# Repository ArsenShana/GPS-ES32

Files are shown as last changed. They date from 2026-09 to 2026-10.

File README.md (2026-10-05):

# AlanaTech GPS — трекер на ESP32 + LoRa E32

```
 [NEO-6M] ──UART──> [ESP32 трекер] ──[E32 433 МГц]))) ~~~ (((  [E32]──> [ESP32 приёмник] ──Wi-Fi──> браузер
```

| Папка | Что это |
|---|---|
| [gps_tracker/](gps_tracker/) | ESP32 + NEO-6M + E32: раз в 5 с отправляет координаты по радио |
| [gps_receiver/](gps_receiver/) | ESP32 + E32: принимает пакеты, подключается к Wi-Fi `New BilimLand Wi-Fi`, показывает карту |

Оба проекта — PlatformIO (VS Code → расширение PlatformIO IDE).

## Плата без проводов и 3D-модель

В `tracker-lab/` добавлены локальный сайт с интерактивной 3D-моделью, симуляция
радиообмена, программно разведённая плата-носитель KiCad и корпус STL/STEP.
Запуск сайта: `cd tracker-lab` → `npm ci` → `npm start`, затем открыть
`http://localhost:4173`. Инструкция по сборке и прошивке: `tracker-lab/README.html`.

Носитель R0 рассчитан на **ESP32-DevKitC V4 WROOM с 38 контактами**, NEO-6M
breakout и E32-433T30D. Это прототип: разъёмы нужно сверить с вашими модулями,
KiCad DRC/ERC и физические испытания ещё не выполнены. Герберы пока не выпущены.
Для носителя добавлены среды `carrier` и `carrier_fake` с AUX на GPIO19;
передача пропускается при ошибке конфигурации E32 или таймауте AUX.

Вторая версия **AT-02 V2** находится в `tracker-lab/v2/` и открывается по
`http://localhost:4173/v2/`. Это собственная SMD-архитектура на STM32L072CBT6
с MAX-M10S, E32-433T20S, USB-C, LiPo/PowerPath, buck-boost 3.3 В и датчиком
движения. Arduino/ESP32-DevKit не используются. Подготовлены нумерованная
KiCad-схема, netlist, компоновка PCB 68×44 мм, корпус и отдельная 3D-модель.
Статус V2 — инженерный проект A0: финальная трассировка, RF, уточнение некоторых
посадочных мест и DRC/ERC ещё нужны; Gerber не выпущены. Ядро логики написано
на C и проверено на компьютере, но полный STM32-порт и физические испытания
пока не выполнены. ESP32-прошивку R0 нельзя загружать в V2.

## Подключение

E32 — одинаково на обеих платах:

| E32-433T30D | ESP32 трекер | ESP32 приёмник |
|---|---|---|
| VCC | **5V (VIN)** — не 3.3V! | **5V (VIN)** |
| GND | GND | GND |
| TXD | GPIO16 | GPIO16 |
| RXD | GPIO17 | GPIO17 |
| M0 | GPIO25 | GPIO25 |
| M1 | GPIO26 | GPIO26 |
| AUX | GPIO27 (можно не подключать) | GPIO27 (можно не подключать) |

Только на трекере — NEO-6M (без GPS прошивайте `tracker_fake`):

| NEO-6M | ESP32 |
|---|---|
| VCC | 3.3V (или 5V, если на модуле есть стабилизатор) |
| GND | GND |
| TX | GPIO32 |
| RX | GPIO33 |

> ⚠️ **Никогда не включайте E32 без антенны** — на мощности 1 Вт выходной каскад сгорит.
> ⚠️ E32-433T30D при передаче берёт до ~700 мА. Питание от USB ноутбука может «проседать» —
> тогда ESP32 перезагружается (brownout). Поставьте конденсатор 470–1000 мкФ между VCC и GND модуля.
> При тесте на столе антенны должны быть на расстоянии хотя бы 1–2 м (1 Вт вплотную перегружает приёмник).

Пины меняются в `include/config.h` каждого проекта.

## Параметры радио

Обе прошивки при старте сами проверяют и при необходимости записывают одинаковую конфигурацию E32:
433 МГц (канал 0x17), адрес 0x0000, UART 9600, скорость в эфире 2.4 кбит/с, FEC, 30 дБм, прозрачный режим.

Формат пакета (≤ 58 байт, один радиопакет E32) описан в `lib/GpsProtocol/GpsProtocol.h`:
```
G,1,1234,1,51.128207,71.430411,347,12.3,9,0.9*50
```

## Прошивка

Плата подключается по Type-C и видна как `USB-SERIAL CH340 (COMx)`. Если порт не появился —
кабель только для зарядки, нужен кабель с передачей данных.

**Режим прошивки.** На этих платах автоматический вход в загрузчик не срабатывает
(ошибка `Wrong boot mode detected (0x13)`), поэтому перед каждой прошивкой:
1. зажать **BOOT**;
2. нажать и отпустить **EN** (RST);
3. отпустить **BOOT** — плата ждёт прошивку, пока её не перезагрузят.

```bash
# трекер
cd gps_tracker
pio run -e tracker -t upload && pio device monitor

# приёмник
cd gps_receiver
pio run -e receiver -t upload && pio device monitor
```

Если PlatformIO не установлен в VS Code, вместо `pio` используйте `py -3.11 -m platformio`.

`lib/GpsProtocol` и `lib/E32` одинаковые в обеих папках — при изменении правьте обе копии.

Ход тестирования и найденные ошибки — в [TESTING.md](TESTING.md).

## Тестирование

### 1. Юнит-тесты протокола (без железа, на ПК)
```bash
cd gps_tracker  && pio test -e native
cd gps_receiver && pio test -e native
```
Проверяют кодирование/декодирование, отбрасывание битых и обрезанных пакетов, помещение в 58 байт, подсчёт потерь.
Нужен gcc в PATH (например, MSYS2 `C:\msys64\mingw64\bin`).

### 2. Проверка каждого модуля (Serial-монитор, 115200)
- Трекер: должно быть `[E32] конфигурация ОК` и строки `[GPS] символов=...` с растущим числом.
  Если `символов=0` — неправильно подключён TX NEO-6M.
- Приёмник: `[E32] конфигурация ОК`, `[WiFi] подключено, IP: ...`.
  Если Wi-Fi не подключился, прошивка печатает код причины и список видимых сетей
  (201 — сеть не найдена: проверьте имя с учётом регистра и что сеть на 2.4 ГГц).

### 3. Радиоканал без GPS (в помещении)
Прошейте трекер тестовой прошивкой — она шлёт координаты по кругу вокруг центра Астаны:
```bash
cd gps_tracker && pio run -e tracker_fake -t upload
```
В логе приёмника появятся строки `[RX] id=1 seq=... fix=1 ...`, на странице `http://<IP приёмника>/` — движущаяся точка.

### 4. Автоматическая проверка связи с ПК
ПК должен быть в той же Wi-Fi сети:
```bash
python gps_receiver/tools/link_test.py <IP приёмника> -t 120
```
В конце — итог: принято / потеряно / % потерь и вердикт.

### 5. Настоящий GPS
Прошейте `-e tracker`, вынесите трекер на улицу или к окну. Холодный старт NEO-6M — до 5 минут
(на модуле замигает светодиод, когда есть фикс). На странице бейдж станет «GPS фикс», на карте появится трек.

## Веб-интерфейс приёмника

| Адрес | Что |
|---|---|
| `/` | карта + данные |
| `/api/last` | последний пакет, JSON |
| `/api/history` | трек (до 200 точек), JSON |
| `/api/status` | статистика приёма, Wi-Fi |
| `POST /api/reset` | сброс статистики |

Также доступно по `http://alanatech-gps.local/` (если сеть/ОС поддерживает mDNS).
Карта грузится из интернета (OpenStreetMap), таблица работает и без него.

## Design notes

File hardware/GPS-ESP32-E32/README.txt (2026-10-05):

GPS-ESP32-E32 — плата-носитель R0, 100 × 78 мм, 2 слоя, FR4 1.6 мм.

Открыть GPS-ESP32-E32.kicad_pro в KiCad. Рядом находятся редактируемая
схема .kicad_sch, разведённая плата .kicad_pcb, локальные библиотеки,
PDF схемы и платы, BOM.csv и отчёты DRC/ERC.

Модули: ESP32-DevKitC V4 WROOM, 38 контактов (19 на сторону,
25.4 мм между рядами); NEO-6M breakout; E32-433T30D.
J2/J3 — гнёзда ESP32, J4 — GPS, J5 — E32, J1 — вход 5 В.
GPS J4: 1=3V3, 2=RX, 3=TX, 4=GND.
E32 J5: 1=M0, 2=M1, 3=RXD, 4=TXD, 5=AUX, 6=5V, 7=GND.

Точная разводка GPIO:
GPS TX -> GPIO16, GPS RX <- GPIO17.
E32 TXD -> GPIO26, E32 RXD <- GPIO27.
E32 M0 <- GPIO25, E32 M1 <- GPIO18, E32 AUX -> GPIO19.
Индикатор: GPIO2 -> R1 330 Ом -> анод D1; катод D1 -> GND.

Прошивка из gps_tracker:
  pio run -e kicad_r0 -t upload
Для демонстрационных координат:
  pio run -e kicad_r0_fake -t upload
Обычные tracker/carrier имеют другую распиновку и не подходят этой разводке.

Питание: внешний стабилизированный источник 5 В / 2 А на J1.
E32 питается от 5 В, GPS — от 3.3 В ESP32. C1 1000 мкФ / 10 В
и C2 100 нФ установлены на шине 5 В возле радио.
JP1 соединяет внешний источник с 5V ESP32: снять перемычку до
подключения USB ESP32. Не подавать автомобильные 12/24 В напрямую.
Перед включением радио подключить подходящую антенну 433 МГц.

Проверено KiCad 10.0.6: DRC — 0 нарушений, 0 неподключённых;
ERC — 0 нарушений. Символы описывают пассивные контакты разъёмов:
ERC не проверяет внутренние цепи модулей и совместимость уровней.
Статус: прототип. До изготовления сверить габариты и порядок контактов
реальных модулей, гнёзда E32, полярность LED и конденсатора, проверить
питание и работу на стенде. Геометрия SMD-площадок упрощена.
Герберы для производства не выпускались.

Повторный экспорт проекта:
  python3 tracker-lab/tools/export_kicad_project.py
PDF и DRC/ERC обновляются отдельно через kicad-cli.

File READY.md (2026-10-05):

# AlanaTech GPS — отчёт о готовности

**Дата:** 2026-09-26 · **Версия:** 0.0.1 beta · **Общий статус:** 🟡 прошивки написаны и работают на платах по отдельности,
**радиосвязь трекер → приёмник пока не подтверждена**.

## Итог в одном абзаце

Обе прошивки написаны, собираются и залиты на платы. Каждый ESP32 видит свой модуль E32 и
записывает в него одинаковые настройки радио. Приёмник подключается к Wi-Fi и показывает веб-страницу
с картой. Трекер каждые 5 секунд отправляет пакет в эфир. Но **приёмник пока не получил ни одного пакета** —
причина в радиочасти (антенны / питание / расстояние), а не в проводах к ESP32 и не в прошивке.
GPS в офисе фикс не поймает — это ожидаемо, для координат нужно окно или улица.

## ✅ Что работает (проверено на железе)

| Компонент | Результат проверки |
|---|---|
| Прошивка приёмника | залита на ESP32 (COM3), запускается |
| Прошивка трекера | залита на ESP32 (COM4), запускается |
| E32 на приёмнике | отвечает, конфигурация `C0 00 00 1A 17 44` записана и прочитана обратно |
| E32 на трекере | отвечает, та же конфигурация — провода UART и M0/M1 исправны |
| Трекер: отправка пакетов | каждые 5 с, пакеты `G,1,<seq>,...*CS` уходят в E32 |
| Приёмник: Wi-Fi | подключён к `New BilimLand Wi-Fi`, IP **192.168.8.183** |
| Приёмник: веб-страница и API | `http://192.168.8.183/`, `/api/status`, `/api/last` отвечают с ПК |
| Протокол пакетов | 7/7 юнит-тестов на ПК: кодирование, контрольная сумма, битые/обрезанные пакеты, ≤ 58 байт |
| Сборка | `tracker`, `tracker_fake`, `receiver` — без ошибок |

## ❌ Что пока не работает

| Проблема | Что известно | Что делать |
|---|---|---|
| **Приёмник не получает пакеты** (ОШ-08) | трекер отправил 8+ пакетов, приёмник получил 0 байт. Провода к ESP32 исключены — оба E32 отвечают | проверить антенны на **обоих** E32, питание VCC от **5V/VIN**, разнести модули на 1–2 м, прошить `tracker_fake` (мощность снижена до 21 дБм) |
| **GPS не отдавал данные** (ОШ-07) | прошивка ждала NEO-6M на D32, а он на D16/D17 | ✅ исправлено в коде, **нужно прошить трекер** |

## ⚠️ Риски

- **Слабый Wi-Fi у приёмника:** −71…−84 дБм, есть разрывы и таймауты запросов. Сеть 2.4 ГГц в этом месте слабая
  (ESP32 не умеет 5 ГГц). Приёмник нужно поставить ближе к роутеру.
- **E32 без антенны сгорает** на мощности 1 Вт. Не включать трекер без антенны.
- **Питание:** E32-433T30D при передаче берёт до ~700 мА — от USB ноутбука возможны просадки.
- **Прошивка вручную:** на этих платах автоматический вход в загрузчик не работает —
  нужно BOOT → EN → отпустить BOOT (описано в README).

## ⏳ Не проверено

| Что | Когда можно проверить |
|---|---|
| Пакеты доходят по радио, % потерь (`link_test.py`) | после решения ОШ-08, в офисе |
| NEO-6M выдаёт NMEA (без фикса) | после прошивки трекера, в офисе |
| GPS-фикс, точка и трек на карте | у окна или на улице, холодный старт до 5 мин |
| Дальность связи | на улице, после всего выше |
| Исправление переподключения Wi-Fi (ОШ-06) | при следующей прошивке приёмника |

## Следующие шаги

1. Проверить антенны и питание 5V на обоих E32, разнести модули на 1–2 м.
2. Прошить трекер `tracker_fake` → убедиться, что `rx_ok` на приёмнике растёт.
3. Прошить трекер `tracker` (исправленные пины GPS) → в логе `символов=...` растёт.
4. Прошить приёмник (исправление Wi-Fi), поставить ближе к роутеру.
5. Вынести трекер к окну/на улицу → фикс, точка на карте.
6. Прогнать `python gps_receiver/tools/link_test.py 192.168.8.183 -t 300` и записать % потерь.

## Оборудование

| Плата | Чип | Порт | MAC | E32 (TXD/RXD/M0/M1) | GPS (TX/RX) |
|---|---|---|---|---|---|
| Приёмник | ESP32-D0WD-V3 | COM3 | b4:bf:e9:fc:07:d0 | D16 / D17 / D25 / D26, AUX D27 | — |
| Трекер | ESP32-D0WD-V3 | COM4 | 30:76:f5:a9:e8:e8 | D16 / D17 / D25 / D26, AUX D27 | D32 / D33 |

Радио: 433 МГц (канал 0x17), адрес 0x0000, 2.4 кбит/с в эфире, FEC, 30 дБм (в `tracker_fake` — 21 дБм).

---
Подробный журнал ошибок — [TESTING.md](TESTING.md) · Подключение и прошивка — [README.md](README.md)

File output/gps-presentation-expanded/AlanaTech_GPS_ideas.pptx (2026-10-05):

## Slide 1

ПРОДУКТОВЫЕ ИДЕИ / ДЛЯ ТИМЛИДА

Куда встроить GPS

18 идей применения: от личных вещей до транспорта и фермы

Иллюстрации — концепты возможной интеграции, не готовые изделия.

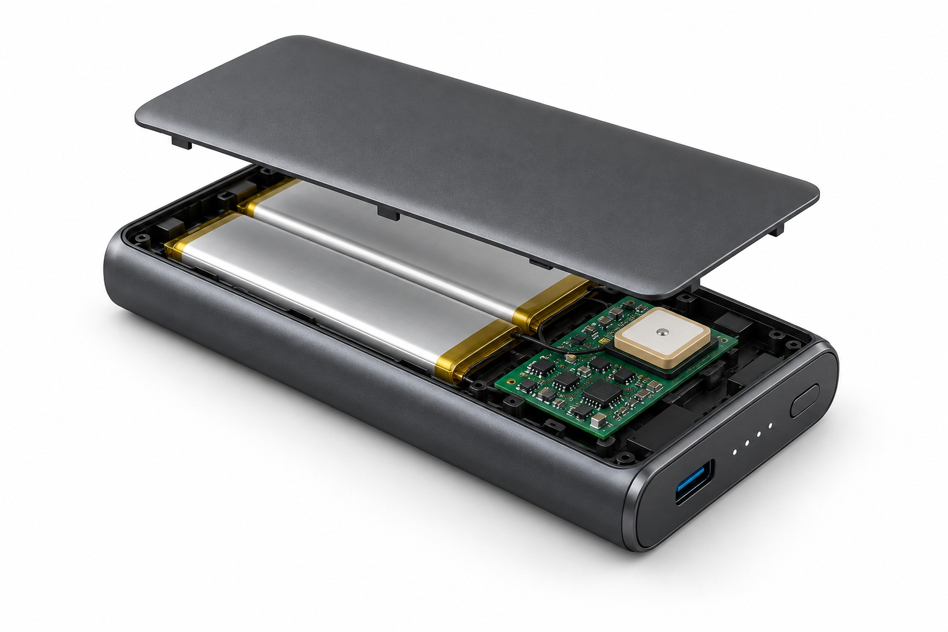
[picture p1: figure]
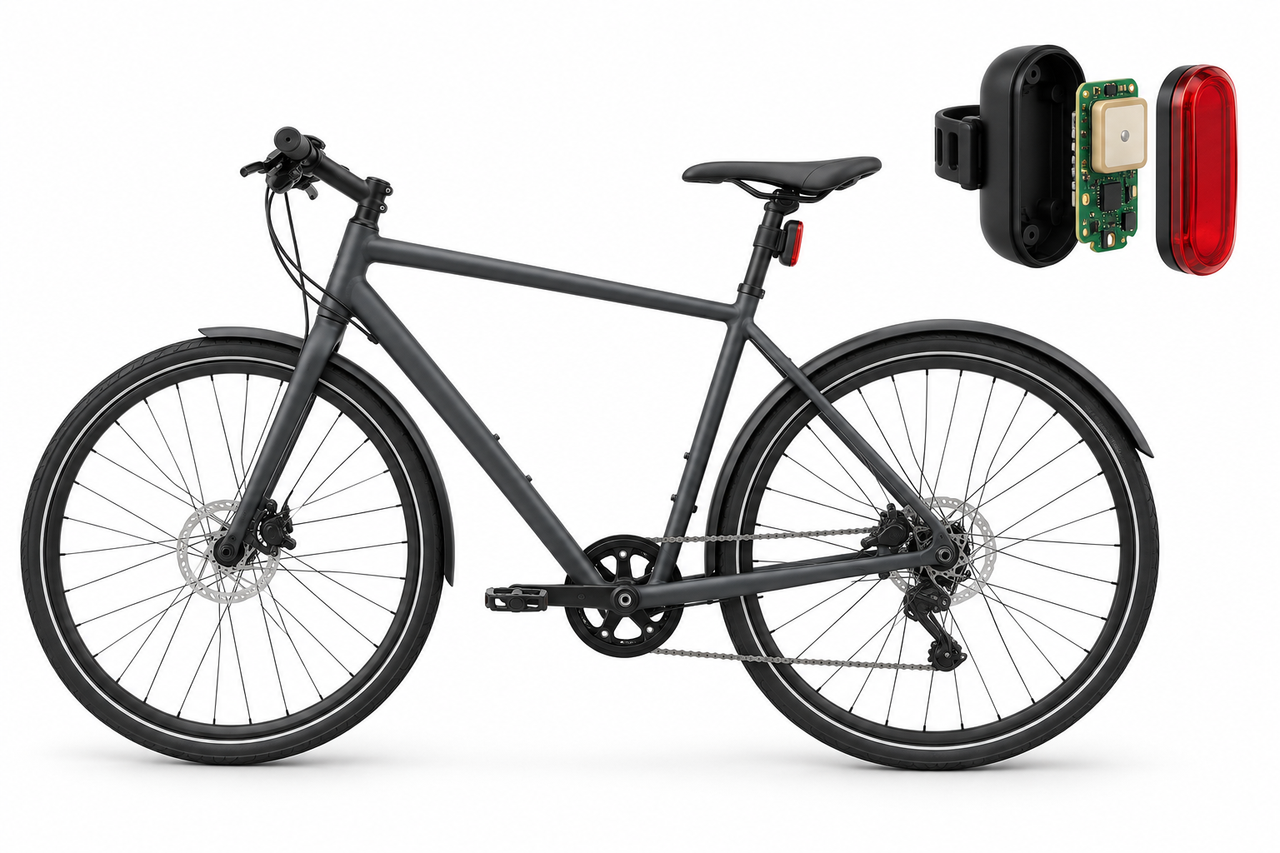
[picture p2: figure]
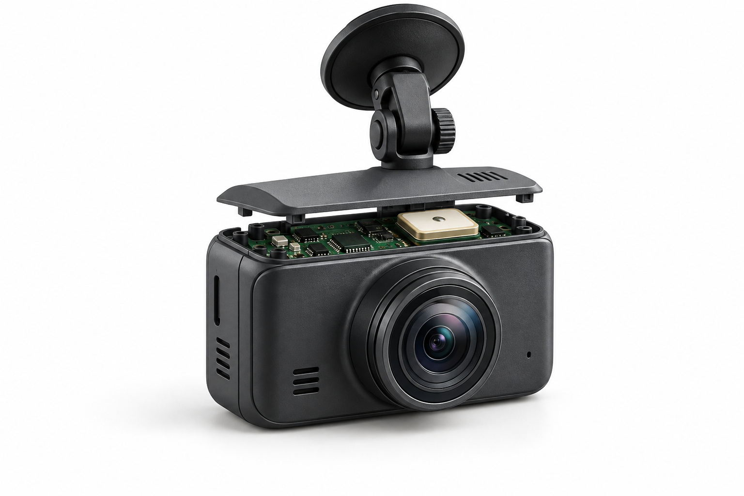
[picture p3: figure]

Пауэрбанк

Питание + поиск устройства

Велосипед

Местоположение + движение

Камера в машине

Видео + маршрут поездки

ALANATECH / GPS • концепции для обсуждения

01

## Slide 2

ОСНОВНОЙ ВАРИАНТ 01

GPS в пауэрбанке

Зарядка телефона и поиск самого устройства в одном корпусе.

Концепт • размещение модуля показано условно

ГДЕ РАЗМЕСТИТЬ

В пластиковом корпусе: модуль и антенна
рядом с платой питания.

ЗАЧЕМ

Показать на карте пауэрбанк или сумку, в
которой он находится.

ЧТО ПРОВЕРИТЬ

Расход заряда, нагрев и качество приёма
рядом с аккумулятором.

Нужны компактная плата и управление питанием

ALANATECH / GPS • концепции для обсуждения

02

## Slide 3

ОСНОВНОЙ ВАРИАНТ 02

GPS в велосипеде

Поиск велосипеда и уведомление о начале движения.

Концепт • размещение модуля показано условно

ГДЕ РАЗМЕСТИТЬ

В заднем фонаре или отдельном
пластиковом блоке под седлом.

ЗАЧЕМ

Видеть последнюю позицию; получать
сигнал о движении при наличии связи.

ЧТО ПРОВЕРИТЬ

Защиту от воды, крепление, зарядку и
приём сигнала рядом с рамой.

Для уведомлений нужен датчик движения

ALANATECH / GPS • концепции для обсуждения

03

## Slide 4

ОСНОВНОЙ ВАРИАНТ 03

GPS в автомобильной камере

Видеорегистратор, который связывает видео с маршрутом поездки.

Концепт • размещение модуля показано условно

ГДЕ РАЗМЕСТИТЬ

В корпусе регистратора или его креплении
у лобового стекла.

ЗАЧЕМ

Записывать координаты, время и скорость
вместе с видео.

ЧТО ПРОВЕРИТЬ

Совместимость с камерой, нагрев на
солнце и питание на парковке.

Удалённый просмотр требует канала связи

ALANATECH / GPS • концепции для обсуждения

04

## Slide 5

ДОПОЛНИТЕЛЬНЫЕ НАПРАВЛЕНИЯ

Ещё три варианта

Идеи для следующего этапа — после проверки основного прототипа.

04

Рюкзак / сумка

Куда: съёмный модуль во
внутреннем кармане.

Польза: поиск своей вещи.

Проверить: зарядку и приём внутри
здания.

05

Кейс инструмента

Куда: отдельный блок под
пластиковой крышкой.

Польза: местоположение
рабочего комплекта.

Проверить: экранирование
металлическими предметами.

06

Электросамокат

Куда: корпус панели или
пластиковый отсек.

Польза: положение и история
поездок.

Проверить: питание, вибрации и
влагозащиту.

ALANATECH / GPS • концепции для обсуждения

05

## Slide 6

НОВЫЕ ИДЕИ / ТРАНСПОРТ

Транспорт и доставка

Ещё три варианта интеграции GPS в подвижные объекты.

Курьерский бокс

КУДА УСТАНОВИТЬ

Под пластиковой крышкой или
в креплении бокса.

ПОЛЬЗА

Маршрут доставки и последняя
позиция.

Для работы по городу нужен
доступный канал связи.

Прицеп / контейнер

КУДА УСТАНОВИТЬ

Во внешнем защищённом
блоке с антенной.

ПОЛЬЗА

Положение груза и история
перемещений.

Металл экранирует; нужна автономная
батарея.

Спецтехника

КУДА УСТАНОВИТЬ

На кабине или в отдельном
корпусе под крышей.

ПОЛЬЗА

Маршрут и время работы на
участке.

Нужно согласовать питание и
защитить от вибраций.

Маршрут показывает перемещение; качество доставки и расход топлива требуют дополнительных данных.

ALANATECH / GPS • концепции для обсуждения

06

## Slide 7

НОВЫЕ ИДЕИ / СЕЛЬСКОЕ ХОЗЯЙСТВО

GPS для фермы

Локальная приёмная станция — основа эксперимента на участке.

Ошейник скота

КУДА УСТАНОВИТЬ

В защищённом лёгком блоке на
ошейнике.

ПОЛЬЗА

Последняя позиция животного
на пастбище.

Проверить крепление, вес и покрытие
связи.

Трактор / агрегат

КУДА УСТАНОВИТЬ

На кабине или раме с открытой
антенной.

ПОЛЬЗА

История проходов и положение
техники.

Точная автопилотная навигация
потребует RTK.

Мобильный насос

КУДА УСТАНОВИТЬ

В корпусе переносного насоса
или тележки.

ПОЛЬЗА

Учёт перемещений между
участками.

Нужны влагозащита и датчик
включения.

Дальность E32 и автономность здесь не заявлены: их нужно измерить на конкретной территории.

ALANATECH / GPS • концепции для обсуждения

07

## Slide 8

НОВЫЕ ИДЕИ / ЛИЧНЫЕ ВЕЩИ

Питомцы, багаж и туризм

Компактный съёмный трекер можно адаптировать к разным креплениям.

Ошейник питомца

КУДА УСТАНОВИТЬ

На ошейнике, в лёгком
съёмном корпусе.

ПОЛЬЗА

Поиск рядом с зоной покрытия
связи.

Нынешняя плата слишком велика;
нужна миниатюризация.

Чемодан

КУДА УСТАНОВИТЬ

Под пластиковой стенкой или в
ручке.

ПОЛЬЗА

Последнее известное
положение багажа.

В помещении GPS нестабилен;
возможна помощь BLE.

Туристический маяк

КУДА УСТАНОВИТЬ

На лямке рюкзака или в
верхнем кармане.

ПОЛЬЗА

Запись маршрута и передача
позиции группе.

Нужны автономность, кнопка SOS и
проверка связи.

Туристический концепт не заменяет сертифицированный аварийный маяк.

ALANATECH / GPS • концепции для обсуждения

08

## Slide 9

НОВЫЕ ИДЕИ / РАБОЧЕЕ ОБОРУДОВАНИЕ

Где находится оборудование

GPS полезен для объектов, которые перевозят между площадками.

Генератор

КУДА УСТАНОВИТЬ

На внешней пластиковой
панели корпуса.

ПОЛЬЗА

Местоположение переносной
установки.

Экранирование металлом, нагрев и
вибрации.

Прокатный инвентарь

КУДА УСТАНОВИТЬ

В креплении или отдельном
защищённом блоке.

ПОЛЬЗА

Учёт выдачи и история
перемещений.

Связать ID трекера с инвентарным
номером.

Измерительный
комплект

КУДА УСТАНОВИТЬ

В крышке транспортного кейса.

ПОЛЬЗА

Поиск полевого комплекта и
журнал выездов.

Время последнего обновления должно
быть видно.

Контроль движения, вскрытия и работы оборудования потребует отдельных датчиков.

ALANATECH / GPS • концепции для обсуждения

09

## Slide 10

ТЕКУЩИЙ ПРОЕКТ

Как работает AlanaTech GPS

ESP32 + NEO-6M + E32-433T30D: координаты передаются на локальную станцию.

01

GPS NEO-6M

Получает сигналы спутников
и определяет координаты.

02

ESP32 + E32

Контроллер формирует
пакет; радио отправляет его
станции.

03

Станция + карта

Приёмник ESP32 получает
пакет и показывает данные в
браузере.

В прошивке базовый интервал отправки — 5 секунд. Это не гарантия доставки.

Локальный браузерный интерфейс; для удалённого доступа нужна дополнительная инфраструктура.

ALANATECH / GPS • концепции для обсуждения

10

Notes: Основа: README.md и gps_tracker/include/config.h. GPS определяет положение; E32 является отдельным радиоканалом. Не путать UART-модуль E32 с готовой сетью LoRaWAN.

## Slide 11

ВЫБОР СВЯЗИ

Как передавать координаты

Способ передачи зависит от территории и сценария.

E32 + станция

КУДА УСТАНОВИТЬ

Ферма, площадка, группа
устройств рядом со станцией.

ПОЛЬЗА

Локальный приём без сотового
модема в каждом трекере.

Нужны покрытие станции и проверка
помех.

Сотовый модем

КУДА УСТАНОВИТЬ

Перемещения по городу и
между населёнными пунктами.

ПОЛЬЗА

Передача в серверный сервис
при наличии сети.

Новые модем, питание, SIM и сервер.

Запись / Bluetooth

КУДА УСТАНОВИТЬ

Личный маршрут и выгрузка
рядом с телефоном.

ПОЛЬЗА

Просмотр после поездки или
при подключении.

Для записи нужна память; BLE не даёт
удалённую связь.

GPS сам по себе не отправляет координаты владельцу.

ALANATECH / GPS • концепции для обсуждения

11

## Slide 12

АППАРАТНАЯ ОСНОВА

Плата KiCad для прототипа

Редактируемые схема и плата-носитель для готовых модулей.

100 × 78 мм

ESP32-DevKitC V4
GPS NEO-6M
E32-433T30D

2 слоя • питание 5 В
Отдельная конфигурация kicad_r0

Уже подготовлено

Схема, разводка, локальные библиотеки, BOM
и PDF.

Проверка KiCad

DRC и ERC: 0 нарушений в отчётах проекта.

Перед изготовлением

Сверить реальные модули, контакты и
посадочные размеры.

ALANATECH / GPS • концепции для обсуждения

12

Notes: Файлы: hardware/GPS-ESP32-E32/. DRC/ERC проверяют заданную модель. Символы разъёмов пассивные; проверка не доказывает совместимость питания и внутренних цепей модулей. Герберы не выпущены. Проект остаётся прототипом.

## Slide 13

ФУНКЦИИ ДЛЯ РАЗВИТИЯ

Что добавить к координатам

Предлагаемые функции следующей версии; сейчас они не заявлены как готовые.

Зона на карте

Уведомление при выходе за границу — при
свежих координатах и связи.

Датчик движения

Пробуждение при движении и события
перемещения.

Заряд и связь

Уровень батареи, время обновления и отметка
потери связи.

История маршрута

Хранение точек и просмотр поездки; нужны
память и интерфейс.

ALANATECH / GPS • концепции для обсуждения

13

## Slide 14

ПОРЯДОК ЭКСПЕРИМЕНТОВ

Что проверять первым

Последовательность предложена по возможности использовать нынешний прототип.

Сценарий

Почему начать

Доработка

Этап

Полевой кейс

Место для модулей

Корпус и питание

Первый пилот

Ферма / техника

Локальная станция

Монтаж и покрытие

Второй пилот

Велосипед

Проверка в движении

Батарея и защита

После стенда

Пауэрбанк

Единый корпус

Малая плата

Новая версия

Питомец / багаж

Компактный продукт

Связь и габариты

Новая версия

Это план экспериментов, а не оценка рынка, стоимости или подтверждённой автономности.

ALANATECH / GPS • концепции для обсуждения

14

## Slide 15

ПРОВЕРКА ПРОТОТИПА

Как понять, что идея работает

Для каждого сценария фиксируем измеримые результаты.

01

Позиция и связь

Проверить время получения координат, доставку пакетов и потери на маршруте.

02

Питание и корпус

Измерить расход энергии, работу при передаче, нагрев и надёжность крепления.

03

Сценарий пользователя

Показать положение, историю и время обновления; проверить пользу на реальном объекте.

ALANATECH / GPS • концепции для обсуждения

15

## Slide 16

СЛЕДУЮЩИЙ ШАГ

Один трекер — разные применения

Начать с полевого кейса, затем адаптировать устройство под выбранный сценарий.

18 идей интеграции

Личные вещи • транспорт • ферма • рабочее оборудование

Для первого пилота: выбрать объект, установить прототип, проверить связь
и показать маршрут на карте.

Результат пилота: реальные измерения и требования к следующей плате.

ALANATECH / GPS • концепции для обсуждения

16

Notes: Иллюстрации первых слайдов — концепты из предыдущей презентации. Все новые интеграции и функции — идеи развития. Техническая база: README.md, gps_tracker/include/config.h, hardware/GPS-ESP32-E32/README.txt и отчёты DRC/ERC. Обновлено 5 октября 2026 года.

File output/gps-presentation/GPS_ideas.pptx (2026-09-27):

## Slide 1

ПРОДУКТОВЫЕ ИДЕИ / ДЛЯ ТИМЛИДА

Куда встроить GPS

Три основных варианта и ещё три направления для развития

Иллюстрации — концепты возможной интеграции, не готовые изделия.


Пауэрбанк

Питание + поиск устройства

Велосипед

Местоположение + движение

Камера в машине

Видео + маршрут поездки

ALANATECH / GPS • концепции для обсуждения

01

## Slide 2

ОСНОВНОЙ ВАРИАНТ 01

GPS в пауэрбанке

Зарядка телефона и поиск самого устройства в одном корпусе.

Концепт • размещение модуля показано условно

ГДЕ РАЗМЕСТИТЬ

В пластиковом корпусе: модуль и антенна
рядом с платой питания.

ЗАЧЕМ

Показать на карте пауэрбанк или сумку, в
которой он находится.

ЧТО ПРОВЕРИТЬ

Расход заряда, нагрев и качество приёма
рядом с аккумулятором.

Кандидат для первого прототипа

ALANATECH / GPS • концепции для обсуждения

02

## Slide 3

ОСНОВНОЙ ВАРИАНТ 02

GPS в велосипеде

Поиск велосипеда и уведомление о начале движения.

Концепт • размещение модуля показано условно

ГДЕ РАЗМЕСТИТЬ

В заднем фонаре или отдельном
пластиковом блоке под седлом.

ЗАЧЕМ

Видеть последнюю позицию; получать
сигнал о движении при наличии связи.

ЧТО ПРОВЕРИТЬ

Защиту от воды, крепление, зарядку и
приём сигнала рядом с рамой.

Для уведомлений нужен датчик движения

ALANATECH / GPS • концепции для обсуждения

03

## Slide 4

ОСНОВНОЙ ВАРИАНТ 03

GPS в автомобильной камере

Видеорегистратор, который связывает видео с маршрутом поездки.

Концепт • размещение модуля показано условно

ГДЕ РАЗМЕСТИТЬ

В корпусе регистратора или его креплении
у лобового стекла.

ЗАЧЕМ

Записывать координаты, время и скорость
вместе с видео.

ЧТО ПРОВЕРИТЬ

Совместимость с камерой, нагрев на
солнце и питание на парковке.

Удалённый просмотр требует канала связи

ALANATECH / GPS • концепции для обсуждения

04

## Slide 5

ДОПОЛНИТЕЛЬНЫЕ НАПРАВЛЕНИЯ

Ещё три варианта

Идеи для следующего этапа — после проверки основного прототипа.

04

Рюкзак / сумка

Куда: съёмный модуль во
внутреннем кармане.

Польза: поиск своей вещи.

Проверить: зарядку и приём внутри
здания.

05

Кейс инструмента

Куда: отдельный блок под
пластиковой крышкой.

Польза: местоположение
рабочего комплекта.

Проверить: экранирование
металлическими предметами.

06

Электросамокат

Куда: корпус панели или
пластиковый отсек.

Польза: положение и история
поездок.

Проверить: питание, вибрации и
влагозащиту.

ALANATECH / GPS • концепции для обсуждения

05

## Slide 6

ПРИНЦИП РАБОТЫ

Как координаты попадут на телефон

GPS определяет положение. Передача координат — отдельная часть системы.

1

GPS / GNSS

Получает сигналы спутников
и определяет координаты.

2

Канал связи

Сотовый модем отправляет
данные при наличии
покрытия.

3

Приложение

Показывает позицию, время
обновления и историю.

›

›

Без модема: можно хранить маршрут в устройстве и выгружать его позже.

Bluetooth подходит для связи рядом с телефоном; для удалённого поиска нужен другой канал.

ALANATECH / GPS • концепции для обсуждения

06

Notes: Схема упрощена. Для удалённого доступа также нужна серверная часть. Доступ к координатам предоставляется владельцу устройства. При потере связи следует отображать время последнего обновления.

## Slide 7

СРАВНЕНИЕ

Что выбрать для первого прототипа

Предварительная оценка концепций; стоимость и автономность ещё предстоит измерить.

Критерий

Пауэрбанк

Велосипед

Автокамера

Главная польза

Поиск устройства

Поиск + движение

Видео + маршрут

Питание

Своя батарея

Отдельная батарея

Бортовая сеть

Главная задача

Расход заряда

Вода и крепление

Связь с камерой

Приоритет идеи

Первый прототип

Следующий вариант

Отдельное направление

Предлагаемый старт: пауэрбанк — готовый запас энергии и место для электроники.

ALANATECH / GPS • концепции для обсуждения

07

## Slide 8

РЕШЕНИЕ ДЛЯ ОБСУЖДЕНИЯ

Начать с GPS-пауэрбанка

Рабочая гипотеза: проверить базовый трекер, затем адаптировать его к другим корпусам.

01

Собрать макет

GPS-модуль, контроллер, питание и выбранный канал связи.

02

Проверить в реальных условиях

Приём на улице и в сумке, расход энергии, передачу координат.

03

Показать результат

Позиция на карте, история маршрута и время последнего обновления.

Обсудить с тимлидом: сценарий поиска, размеры корпуса и желаемую автономность.

ALANATECH / GPS • концепции для обсуждения

08

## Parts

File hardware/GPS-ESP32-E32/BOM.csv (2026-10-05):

Reference | Quantity | Part | Notes
U1 | 1 | ESP32-DevKitC V4 WROOM | 38 contacts, 25.4 mm between rows; not WROVER
U2 | 1 | NEO-6M breakout + patch antenna | verify board size and VCC RX TX GND order; 3.3V capable
U3 | 1 | EBYTE E32-433T30D | 24 x 43 mm, UART 3.3V, 5V supply
J2 J3 | 2 | Female header 1x19 2.54 mm | through-hole sockets for ESP32
J4 | 1 | Female header 1x04 2.54 mm | verify module orientation
J5 | 1 | Right-angle female header 1x07 2.54 mm | verify pin orientation and horizontal module height
J1 | 1 | Screw terminal 1x02 5.08 mm | 5V regulated input, >=2A
JP1 | 1 | Header 1x02 2.54 mm + shunt | disconnect before USB programming
C1 | 1 | 1000uF 10V low-ESR electrolytic | diameter <=8 mm height <=12 mm pitch 4 mm
C2 | 1 | 100nF X7R 0805 | >=10V
R1 | 1 | 330 Ohm 0805 | LED series resistor
D1 | 1 | Green LED 0805 | A/K orientation required
ANT | 1 | 433 MHz SMA antenna | match E32 SMA connector
PSU | 1 | Regulated 5V 2A supply | not connected directly to vehicle 12/24V
H1-H4 | 8 | M3 screws | 4 for PCB posts, 4 for lid; length verified after trial print

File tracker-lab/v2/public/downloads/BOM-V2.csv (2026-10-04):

Ref | Value | Layer | X mm | Y mm | Status
U1 | STM32L072CBT6 | F.Cu | 31.5 | 18 | Selection/land pattern verification required
U2 | u-blox MAX-M10S | B.Cu | 14 | 13 | Selection/land pattern verification required
U3 | EBYTE E32-433T20S | F.Cu | 56 | 20 | Selection/land pattern verification required
U4 | TI BQ24074 | F.Cu | 21 | 34 | Selection/land pattern verification required
U5 | TI TPS63031 | F.Cu | 31.5 | 34 | Selection/land pattern verification required
U6 | ST LIS2DW12 | F.Cu | 40 | 10 | Selection/land pattern verification required
U7 | TI TPS22919 | F.Cu | 22 | 25 | Selection/land pattern verification required
J1 | USB-C / USB 2.0 | F.Cu | 12 | 41 | Selection/land pattern verification required
J2 | LiPo / NTC · 3 контакта | F.Cu | 37 | 5 | Selection/land pattern verification required
L1 | Дроссель 2.2 µH | F.Cu | 36.5 | 34 | Selection/land pattern verification required
J3 | GNSS RF / u.FL | F.Cu | 8 | 25 | Selection/land pattern verification required
SW1 | BOOT / DFU | F.Cu | 43 | 37.5 | Selection/land pattern verification required
SW2 | RESET | F.Cu | 49 | 37.5 | Selection/land pattern verification required
R1 | 5.1k / CC1 | F.Cu | 6 | 35 | Selection/land pattern verification required
R2 | 5.1k / CC2 | F.Cu | 6 | 37.5 | Selection/land pattern verification required
R3 | 22R / USB D+ | F.Cu | 18 | 29 | Selection/land pattern verification required
R4 | 22R / USB D- | F.Cu | 18 | 31 | Selection/land pattern verification required
R5 | 10k / BOOT0 | F.Cu | 40 | 34 | Selection/land pattern verification required
R6 | 10k / NRST | F.Cu | 44 | 31 | Selection/land pattern verification required
R7 | 1M / battery divider | F.Cu | 25 | 8 | Selection/land pattern verification required
R8 | 330k / battery divider | F.Cu | 25 | 10.5 | Selection/land pattern verification required
R9 | 10k / I2C SCL | F.Cu | 36 | 9 | Selection/land pattern verification required
R10 | 10k / I2C SDA | F.Cu | 36 | 11.5 | Selection/land pattern verification required
R11 | 330R / LED | F.Cu | 42 | 28 | Selection/land pattern verification required
R12 | 100k / EN1 default | F.Cu | 23 | 39 | Selection/land pattern verification required
R13 | 2.94k / ISET 300mA target | F.Cu | 23 | 31 | Selection/land pattern verification required
R14 | 3.24k / ILIM | F.Cu | 19.5 | 37.5 | Selection/land pattern verification required
R15 | 46.4k / safety timer | F.Cu | 26 | 37.5 | Selection/land pattern verification required
R16 | 1k / ITERM | F.Cu | 26 | 31 | Selection/land pattern verification required
R17 | 10k / CHG pullup | F.Cu | 28 | 6 | Selection/land pattern verification required
R18 | 100R / GNSS QOD | F.Cu | 19 | 24.5 | Selection/land pattern verification required
R19 | 10k / radio reset pullup | F.Cu | 44 | 18 | Selection/land pattern verification required
R20 | 100k / M0 pulldown | F.Cu | 44 | 20.5 | Selection/land pattern verification required
R21 | 100k / M1 pulldown | F.Cu | 44 | 23 | Selection/land pattern verification required
C1 | 100nF / VDD1 | F.Cu | 24.5 | 16.5 | Selection/land pattern verification required
C2 | 100nF / VDD24 | F.Cu | 30 | 25 | Selection/land pattern verification required
C3 | 100nF / VDD48 | F.Cu | 32 | 11 | Selection/land pattern verification required
C4 | 100nF / USB VDD | F.Cu | 38 | 18 | Selection/land pattern verification required
C5 | 100nF / VDDA | F.Cu | 25 | 18.5 | Selection/land pattern verification required
C6 | 4.7uF / MCU | F.Cu | 28 | 27 | Selection/land pattern verification required
C7 | 100nF / reset | F.Cu | 46 | 28 | Selection/land pattern verification required
C8 | 100nF / ADC | F.Cu | 25 | 13 | Selection/land pattern verification required
C9 | 1uF / GNSS VIO | B.Cu | 9 | 19 | Selection/land pattern verification required
C10 | 10uF / GNSS VCC | B.Cu | 19 | 19 | Selection/land pattern verification required
C11 | 1uF / GNSS backup | B.Cu | 19 | 7 | Selection/land pattern verification required
C12 | 100nF / motion | F.Cu | 40 | 7 | Selection/land pattern verification required
C13 | 10uF / motion | F.Cu | 42.5 | 13 | Selection/land pattern verification required
C14 | 10uF / USB IN | F.Cu | 17 | 35 | Selection/land pattern verification required
C15 | 10uF / battery | F.Cu | 33 | 7 | Selection/land pattern verification required
C16 | 22uF / VSYS | F.Cu | 28 | 34 | Selection/land pattern verification required
C17 | 10uF / buck-boost IN | F.Cu | 31 | 38.5 | Selection/land pattern verification required
C18 | 22uF / buck-boost OUT | F.Cu | 36 | 39 | Selection/land pattern verification required
C19 | 22uF / buck-boost OUT | F.Cu | 36 | 41.5 | Selection/land pattern verification required
C20 | 100uF / radio buffer | F.Cu | 60 | 37 | Selection/land pattern verification required
C21 | 100nF / radio | F.Cu | 62.5 | 8 | Selection/land pattern verification required
FB1 | Ferrite / analog supply | F.Cu | 25 | 21 | Selection/land pattern verification required
D1 | Green LED / status | F.Cu | 42 | 25 | Selection/land pattern verification required
U8 | USBLC6-2SC6 / ESD | F.Cu | 15 | 32.5 | Selection/land pattern verification required
J4 | SWD / pogo | B.Cu | 34 | 8 | Selection/land pattern verification required
ANT1 | GNSS patch 18x18 - MPN and matching pending | F.Cu | 14 | 13 | RF validation required
BAT1 | Protected LiPo 1S + NTC / 50x30x6 max | Off-board | 9 | 7 | Capacity chosen after current measurement

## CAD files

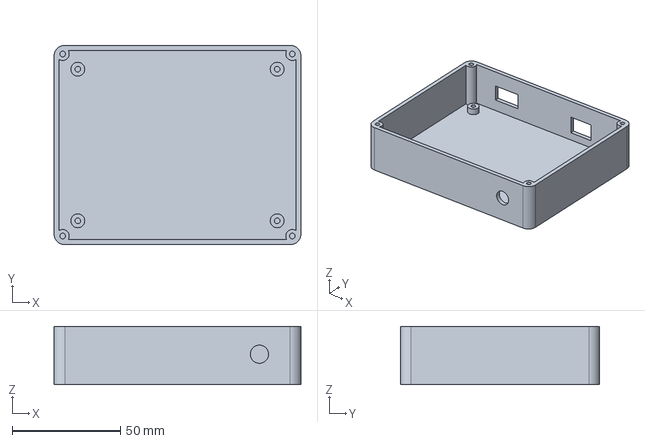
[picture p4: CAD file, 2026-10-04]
tracker-lab/public/downloads/enclosure-base.step
114.0 x 92.0 x 27.0 mm

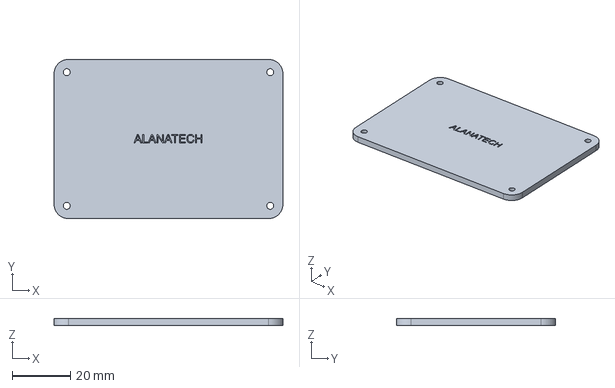
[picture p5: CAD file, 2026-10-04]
tracker-lab/v2/public/downloads/enclosure-lid.step
78.8 x 54.8 x 2.40 mm

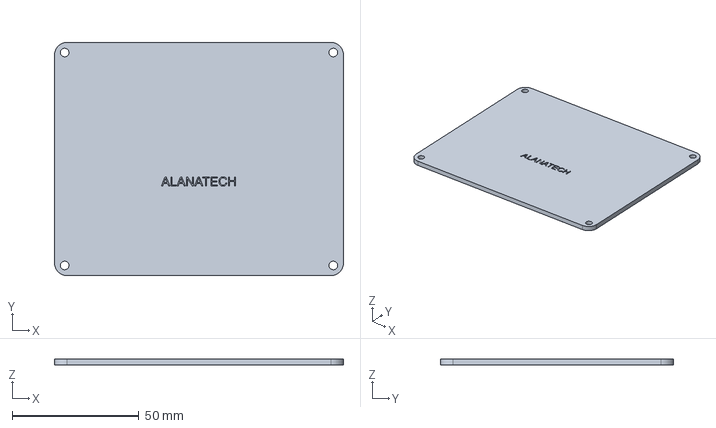
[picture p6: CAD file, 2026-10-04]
tracker-lab/public/downloads/enclosure-lid.step
114.0 x 92.0 x 2.40 mm

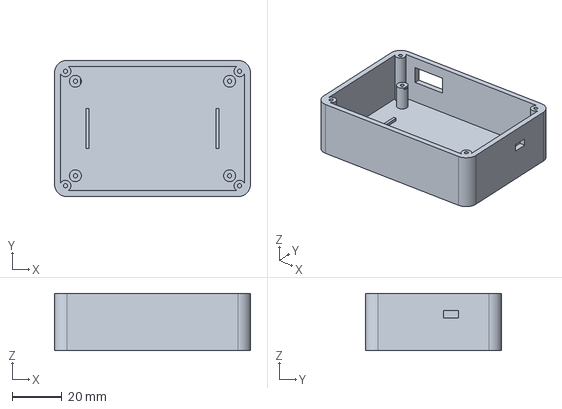
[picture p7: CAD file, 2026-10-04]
tracker-lab/v2/public/downloads/enclosure-base.step
78.8 x 54.8 x 23.0 mm

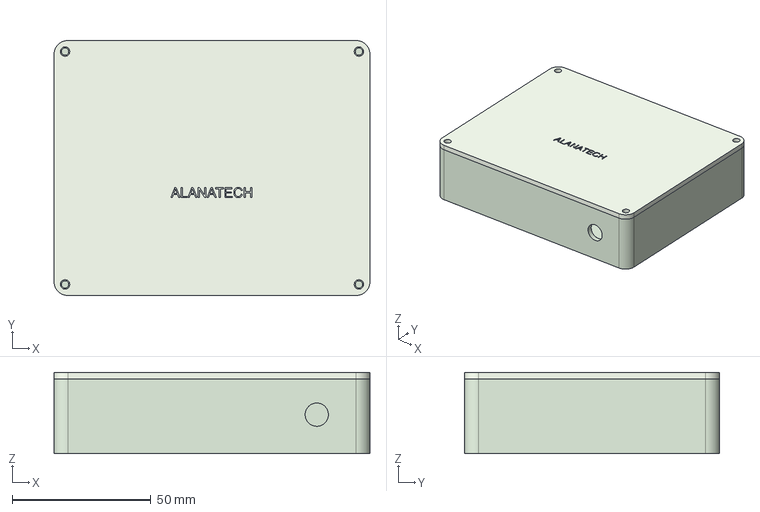
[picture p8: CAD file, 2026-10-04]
tracker-lab/public/downloads/enclosure.step
114.0 x 92.0 x 29.4 mm
base
lid

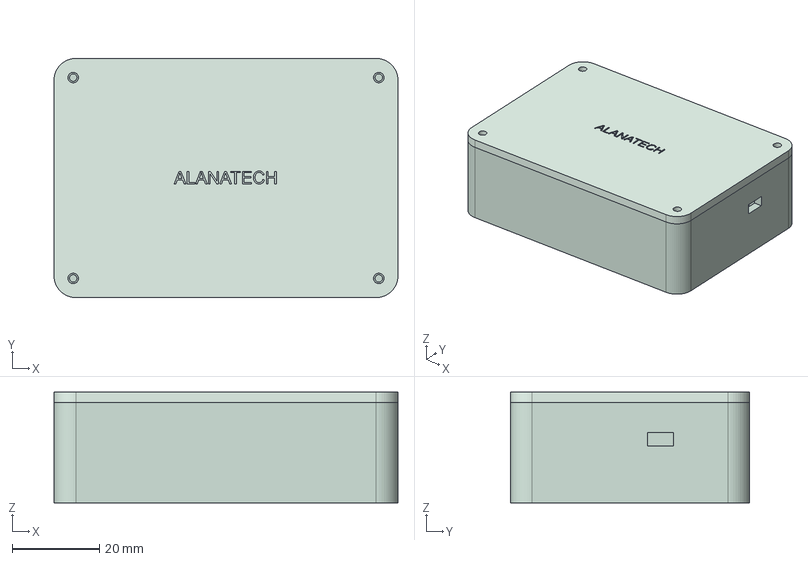
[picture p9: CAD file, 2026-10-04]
tracker-lab/v2/public/downloads/enclosure.step
78.8 x 54.8 x 25.4 mm
base
lid

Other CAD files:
tracker-lab/public/downloads/enclosure-base.stl
tracker-lab/public/downloads/enclosure-lid.stl
tracker-lab/v2/public/downloads/enclosure-base.stl
tracker-lab/v2/public/downloads/enclosure-lid.stl

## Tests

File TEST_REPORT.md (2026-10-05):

# Отчёт о тестировании протокола GPS-ES32

**Дата:** 2026-10-05 · **Что проверялось:** `lib/GpsProtocol/GpsProtocol.h`
(кодирование/декодирование пакета) и драйвер `lib/E32/E32.h` — статический
разбор. Обе копии (`gps_tracker/` и `gps_receiver/`) идентичны.

## Итог

| Проверка | Результат |
|---|---|
| Юнит-тесты протокола (12 шт.) | ✅ 12 passed, 0 failed |
| Граничные probe-кейсы (nan/inf, пустые/лишние поля, worst-case 58 Б, CRLF) | ✅ все прошли |
| Строгая сборка `-Wall -Wextra -Wconversion -Wsign-conversion` | ✅ 0 предупреждений (после фикса) |
| Worst-case длина пакета | **58 байт** — ровно один подпакет E32, фрагментации нет |

**Вывод:** функциональных багов в протоколе и E32-драйвере не найдено. Код
корректно отбрасывает битые/обрезанные/переполненные пакеты и укладывается в
58 байт. Исправлен один дефект чистоты (знаковое приведение, см. ниже) и
расширен набор регрессионных тестов.

## Исправлено

### Б-01. Знаковое приведение `int → size_t` в `encode()`
- **Файл:** `lib/GpsProtocol/GpsProtocol.h:68` (обе копии)
- **Симптом:** строгий компилятор (`-Wsign-conversion`) выдавал 2 предупреждения
  на `cap - n` и `checksum(out, n)` — `n` объявлен `int`, а параметры `size_t`.
- **Риск:** на практике безопасно (`n` здесь всегда ≥ 0 и ≤ 54), но неявное
  знаковое приведение — потенциальная ловушка при будущих правках формата.
- **Фикс:** явные приведения `cap - (size_t)n` и `checksum(out, (size_t)n)`.
  Поведение не изменилось, предупреждения устранены.

## Добавлены регрессионные тесты

В `test/test_protocol/test_main.cpp` (обе копии) — 5 новых кейсов, фиксирующих
устойчивое поведение декодера:

| Тест | Что проверяет |
|---|---|
| `test_empty_and_trailing_junk_fields_rejected` | Пустое поле (`G,,2,…`) и хвост после числа (`1x`) отбрасываются |
| `test_wrong_field_count_rejected` | 8 или 10 полей вместо 9 → reject, без переполнения массива `f[9]` |
| `test_nan_inf_rejected` | `nan`/`inf`/`-inf` в координатах не проходят как валидные (хотя `strtod` их парсит) |
| `test_missing_checksum_rejected` | Пакет без `*HH` отбрасывается |
| `test_no_newline_accepted` | Строка без завершающего `\n`, но с `*HH`, корректно разбирается |
| `test_lost_packets` (дополнен) | `lostBetween(10,10)=65535` — подтверждает, что приёмник **обязан** проверять `seq != prev` перед подсчётом потерь (это уже сделано в `onPacket`) |

## Как воспроизвести

### Канонично (как в CI проекта) — нужен PlatformIO + gcc
```bash
cd gps_tracker  && pio test -e native
cd gps_receiver && pio test -e native
```

### Быстрый прогон на хосте без PlatformIO (macOS/Linux, нужен только g++)
Лёгкий Unity-совместимый шим лежит в `tests_host/`.
```bash
# из корня репозитория
g++ -std=c++17 -O2 -I gps_tracker/lib/GpsProtocol -I tests_host \
    gps_tracker/test/test_protocol/test_main.cpp -o /tmp/runtests && /tmp/runtests

# строгая проверка предупреждений
g++ -std=c++17 -Wall -Wextra -Wconversion -Wsign-conversion \
    -I gps_tracker/lib/GpsProtocol -I tests_host \
    gps_tracker/test/test_protocol/test_main.cpp -o /tmp/strict   # должно быть 0 warnings

# дополнительный probe-харнесс (граничные случаи)
g++ -std=c++17 -O2 -I gps_tracker/lib/GpsProtocol tests_host/probe.cpp -o /tmp/probe && /tmp/probe
```

## Что НЕ покрыто (нужно железо)

Статический разбор `E32.h` замечаний не дал, но тайминги AUX, запись конфигурации
во flash модуля, brownout при 1 Вт и реальный радиоканал проверяются только на
стенде — см. процедуру в [TESTING.md](TESTING.md) и чек-лист в README.

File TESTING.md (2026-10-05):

# Журнал тестирования

Сюда записываются результаты проверок и все ошибки, найденные во время тестирования:
что случилось, почему и как исправлено. Новые записи — сверху в каждом разделе.

## Текущий статус

| Что | Статус | Дата |
|---|---|---|
| Юнит-тесты протокола (`pio test -e native`), обе папки | ✅ 7/7 | 2026-09-26 |
| Сборка `tracker`, `tracker_fake`, `receiver` | ✅ | 2026-09-26 |
| Приёмник: прошивка на плату | ✅ | 2026-09-26 |
| Приёмник: E32 отвечает, конфигурация записана | ✅ | 2026-09-26 |
| Приёмник: Wi-Fi, веб-сервер (`http://192.168.8.183/`) | ✅ сигнал слабый, −71…−84 дБм, бывают таймауты запросов | 2026-09-26 |
| Приёмник: исправление переподключения Wi-Fi (ОШ-06) | ⏳ собрано, не прошито | 2026-09-26 |
| Трекер: прошивка на плату (COM4) | ✅ | 2026-09-26 |
| Трекер: E32 отвечает, конфигурация записана | ✅ | 2026-09-26 |
| Трекер: NEO-6M (ОШ-07) | ❌ 0 символов → пины исправлены на D16/D17, не прошито | 2026-09-26 |
| Радиоканал трекер → приёмник (ОШ-08) | ❌ трекер отправил 8 пакетов, приёмник получил 0 байт | 2026-09-26 |
| `link_test.py`: потери пакетов | ⏳ не начато | |
| Настоящий GPS (NEO-6M, фикс на улице) | ⏳ не начато | |

## Оборудование

| Плата | Чип | USB | Порт | MAC |
|---|---|---|---|---|
| Приёмник | ESP32-D0WD-V3 (rev v3.1) | CH340 | COM3 | b4:bf:e9:fc:07:d0 |
| Трекер | ESP32-D0WD-V3 (rev v3.1) | CH340 | COM4 | 30:76:f5:a9:e8:e8 |

## Ошибки

### ОШ-09. M0/M1 трекерного E32 на D17/D5, а прошивка управляла D25/D18
- **Дата:** 2026-10-04 · **Плата:** трекер
- **Симптом:** конфигурация E32 читается и пишется, `[TX]` уходят, приёмник не получает ничего (см. ОШ-08).
- **Причина:** M1 физически на D5. D18 не подключён, M1 оставался HIGH — после старта модуль
  не переходил в Normal (M0=0, M1=0) и не передавал. Режим Sleep (M0=M1=1) при этом работал, поэтому конфиг читался.
- **Также:** M0 физически на D17 (прошивка держала там TX к GPS, idle HIGH → M0=1).
- **Исправление:** `E32_M0_PIN 17`, `GPS_TX_PIN -1`, `E32_M1_PIN 5` в [gps_tracker/include/config.h](gps_tracker/include/config.h), прошито (`env:bench`, 21 дБм).
  Заодно прошиты исправленные пины GPS (ОШ-07) — NEO-6M отдаёт NMEA. Приём пакетов после исправления пока 0 — ОШ-08 открыта.

### ОШ-08. Приёмник не получает пакеты от трекера
- **Дата:** 2026-09-26 · **Плата:** трекер + приёмник
- **Симптом:** трекер отправляет каждые 5 с (`[TX] G,1,0,0,0.000000,...*63`, seq 0…7),
  приёмник: `rx_ok=0 rx_bad=0` — не пришло ни одного байта.
- **Что уже исключено:** провода UART и M0/M1 у обоих E32 исправны — оба модуля ответили своим ESP32
  и приняли одинаковую конфигурацию (`ADDH=00 ADDL=00 SPED=1A CHAN=17 OPTION=44`).
- **Возможные причины:** нет антенны на одном из модулей; модули ближе 1 м на мощности 1 Вт
  (перегрузка приёмника); просадка питания E32 при передаче.
- **Что сделано:** в `tracker_fake` мощность снижена до 21 дБм (`-DE32_POWER=3`) для теста на столе.
  Проверить антенны и питание 5V/VIN на обоих E32. **Статус: в работе.**

### ОШ-07. NEO-6M не отдаёт данные — `символов=0`
- **Дата:** 2026-09-26 · **Плата:** трекер
- **Симптом:** `[GPS] символов=0 ... !!! нет данных от NEO-6M — проверьте ... GPIO 32`.
- **Причина:** NEO-6M физически подключён к D16/D17 (поэтому они и были «заняты»), а прошивка ждала его на D32/D33.
- **Исправление:** `GPS_RX_PIN 16`, `GPS_TX_PIN 17` в [gps_tracker/include/config.h](gps_tracker/include/config.h),
  README обновлён. Собрано, **на плату ещё не записано**.
### ОШ-06. Ошибка `sta is connecting, return error` после потери Wi-Fi
- **Дата:** 2026-09-26 · **Плата:** приёмник
- **Симптом:** через ~40 с после старта в логе:
  ```
  [WiFi] соединение потеряно
  E (42815) wifi:sta is connecting, return error
  [E][WiFiSTA.cpp:317] begin(): connect failed! 0x3007
  ```
  Через несколько секунд соединение восстановилось само.
- **Причина:** 1) слабый сигнал 2.4 ГГц (−75 дБм) — соединение рвётся; 2) прошивка каждые 15 с
  вызывала `WiFi.reconnect()` одновременно со встроенным автопереподключением ESP32.
- **Исправление:** прошивка теперь вмешивается, только если ESP32 не подключилась сама за 20 с,
  и печатает код причины отключения. Собрано, **на плату ещё не записано**.
- **Рекомендация:** поставить приёмник ближе к роутеру.

### ОШ-05. Wi-Fi не подключается — код 201 (сеть не найдена)
- **Дата:** 2026-09-26 · **Плата:** приёмник
- **Симптом:** `[WiFi] !!! не удалось подключиться (причина: 201)`.
- **Причина:** в прошивке было имя `New BilimLand WI-FI`, а настоящее — `New BilimLand Wi-Fi`.
  ESP32 сравнивает имя сети с учётом регистра.
- **Исправление:** `WIFI_SSID` в [gps_receiver/include/config.h](gps_receiver/include/config.h). После этого
  подключилось сразу: IP 192.168.8.183.
- **Как нашли:** `netsh wlan show networks mode=bssid` на ПК. Там же видно, что эта сеть на 2.4 ГГц
  (только его видит ESP32) слабая, у ПК сильный только сигнал 5 ГГц.

### ОШ-04. Сканирование Wi-Fi не показывало ни одной сети
- **Дата:** 2026-09-26 · **Плата:** приёмник
- **Симптом:** после неудачного подключения диагностика печатала пустой список сетей.
- **Причина:** `WiFi.scanNetworks()` не работает, пока ESP32 пытается подключиться.
- **Исправление:** перед сканированием `WiFi.disconnect()`, после — снова `WiFi.begin()`,
  печатается количество найденных сетей.

### ОШ-03. Прошивка не запускается: `Wrong boot mode detected (0x13)`
- **Дата:** 2026-09-26 · **Плата:** приёмник
- **Симптом:** `A fatal error occurred: Failed to connect to Espressif device: Wrong boot mode detected (0x13)!`
  Иногда наоборот: после прошивки плата висит в `waiting for download` (BOOT ещё зажата).
- **Причина:** на плате не срабатывает автоматический вход в режим прошивки через CH340.
- **Решение:** вручную: зажать BOOT → нажать и отпустить EN → отпустить BOOT, потом прошивать.
  Команда `pio run -t upload` сама перезагружает плату и выводит её из этого режима — если попытка
  не удалась, повторить BOOT+EN.

### ОШ-02. Плата не видна в Windows
- **Дата:** 2026-09-26 · **Плата:** приёмник
- **Симптом:** после подключения по Type-C не появилось ни COM-порта, ни неизвестного устройства.
- **Причина:** кабель только для зарядки.
- **Решение:** другой кабель → появился `USB-SERIAL CH340 (COM3)`, драйвер уже был установлен.

### ОШ-01. Нельзя поставить PlatformIO
- **Дата:** 2026-09-26 · **ПК**
- **Симптом:** `python -m pip` → `No module named pip`.
- **Причина:** команда `python` в PATH указывает на venv другой программы (hermes-agent) без pip.
- **Решение:** использовать системный Python: `py -3.11 -m pip install --user platformio`,
  запуск — `py -3.11 -m platformio ...`. Для юнит-тестов нужен gcc: `C:\msys64\mingw64\bin` в PATH.

## Шаблон новой записи

```markdown
### ОШ-NN. Коротко, что сломалось
- **Дата:** ГГГГ-ММ-ДД · **Плата:** трекер / приёмник / ПК
- **Симптом:** что видно (лог, поведение)
- **Причина:** почему
- **Исправление:** что поменяли (файл) / **Решение:** что сделать руками
```

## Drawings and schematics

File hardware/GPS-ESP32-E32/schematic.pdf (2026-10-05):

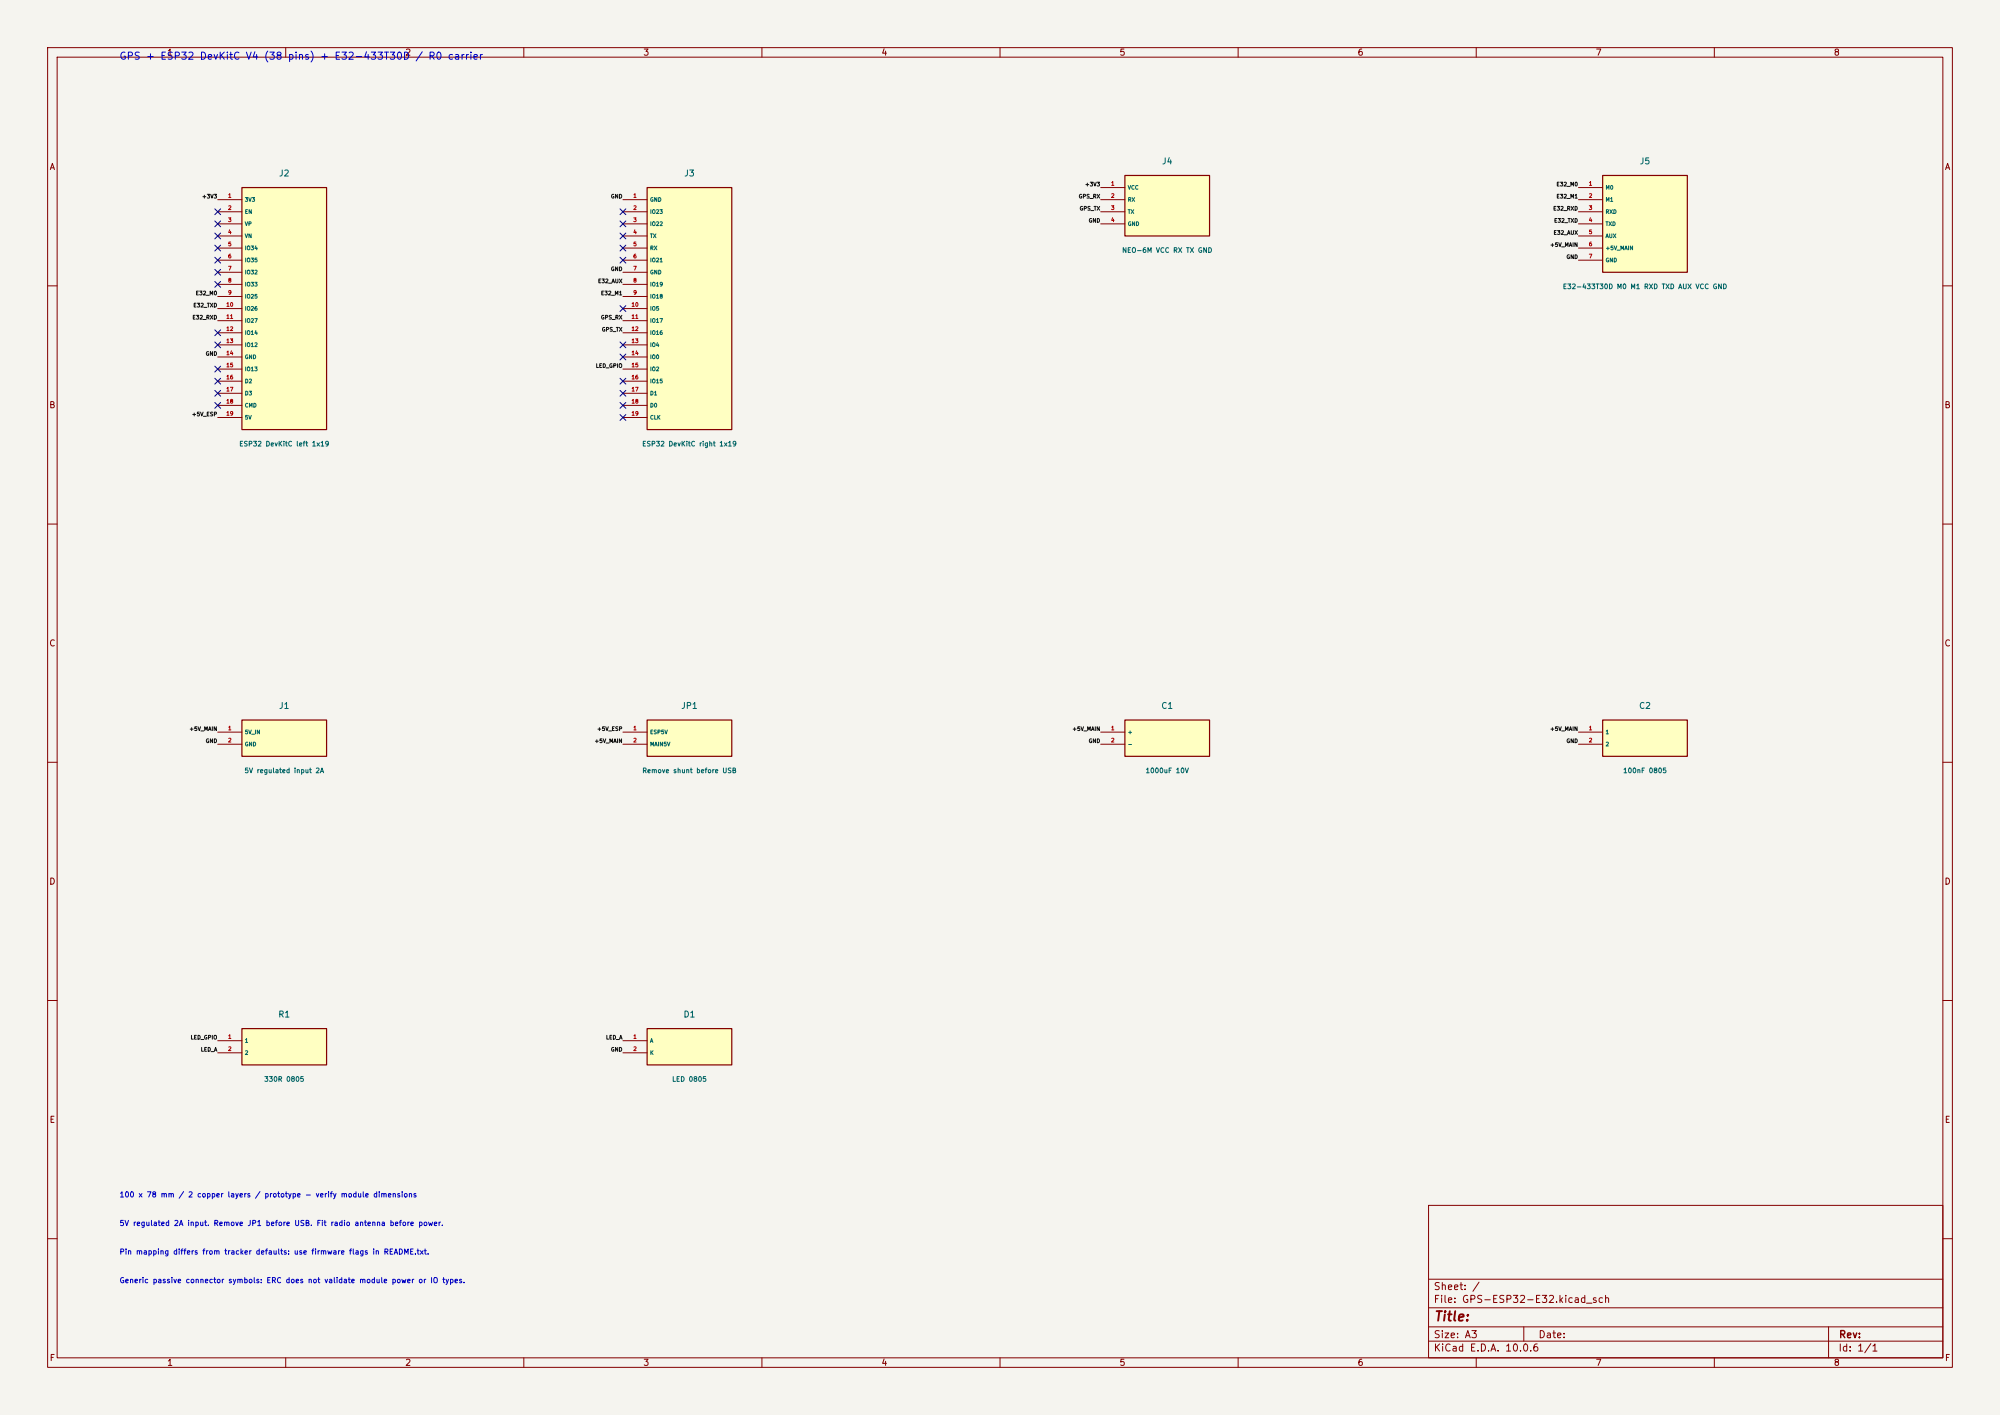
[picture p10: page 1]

NEO-6M VCC RX TX GND

E32-433T30D M0 M1 RXD TXD AUX VCC GND

Remove shunt before USB

100 x 78 mm / 2 copper layers / prototype - verify module dimensions 5V regulated 2A input. Remove JP1 before USB. Fit radio antenna before power. Pin mapping differs from tracker defaults: use firmware flags in README.txt. Generic passive connector symbols: ERC does not validate module power or IO types.

Size: A3 | Rev: | F Date:
KiCad E.D.A. 10.0.6 | Id: 1/1

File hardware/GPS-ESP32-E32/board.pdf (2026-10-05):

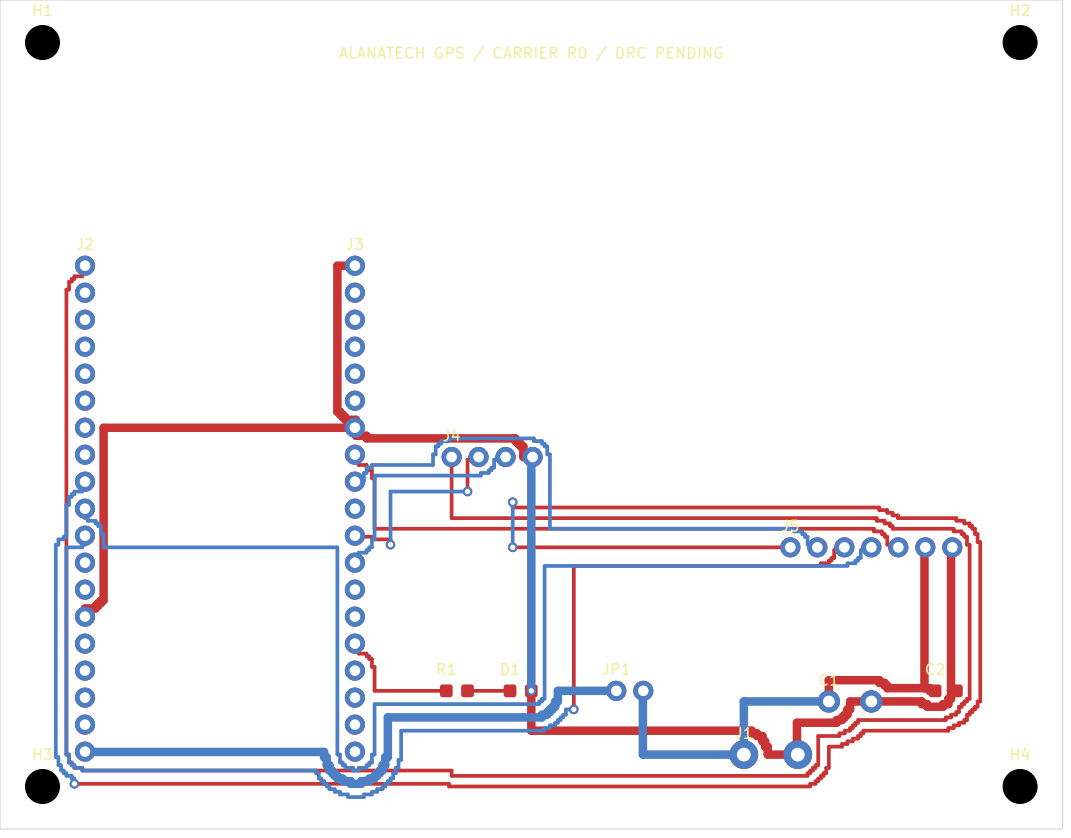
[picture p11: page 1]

ALANATECH GPS / CARRIER R0 / DRC PENDING

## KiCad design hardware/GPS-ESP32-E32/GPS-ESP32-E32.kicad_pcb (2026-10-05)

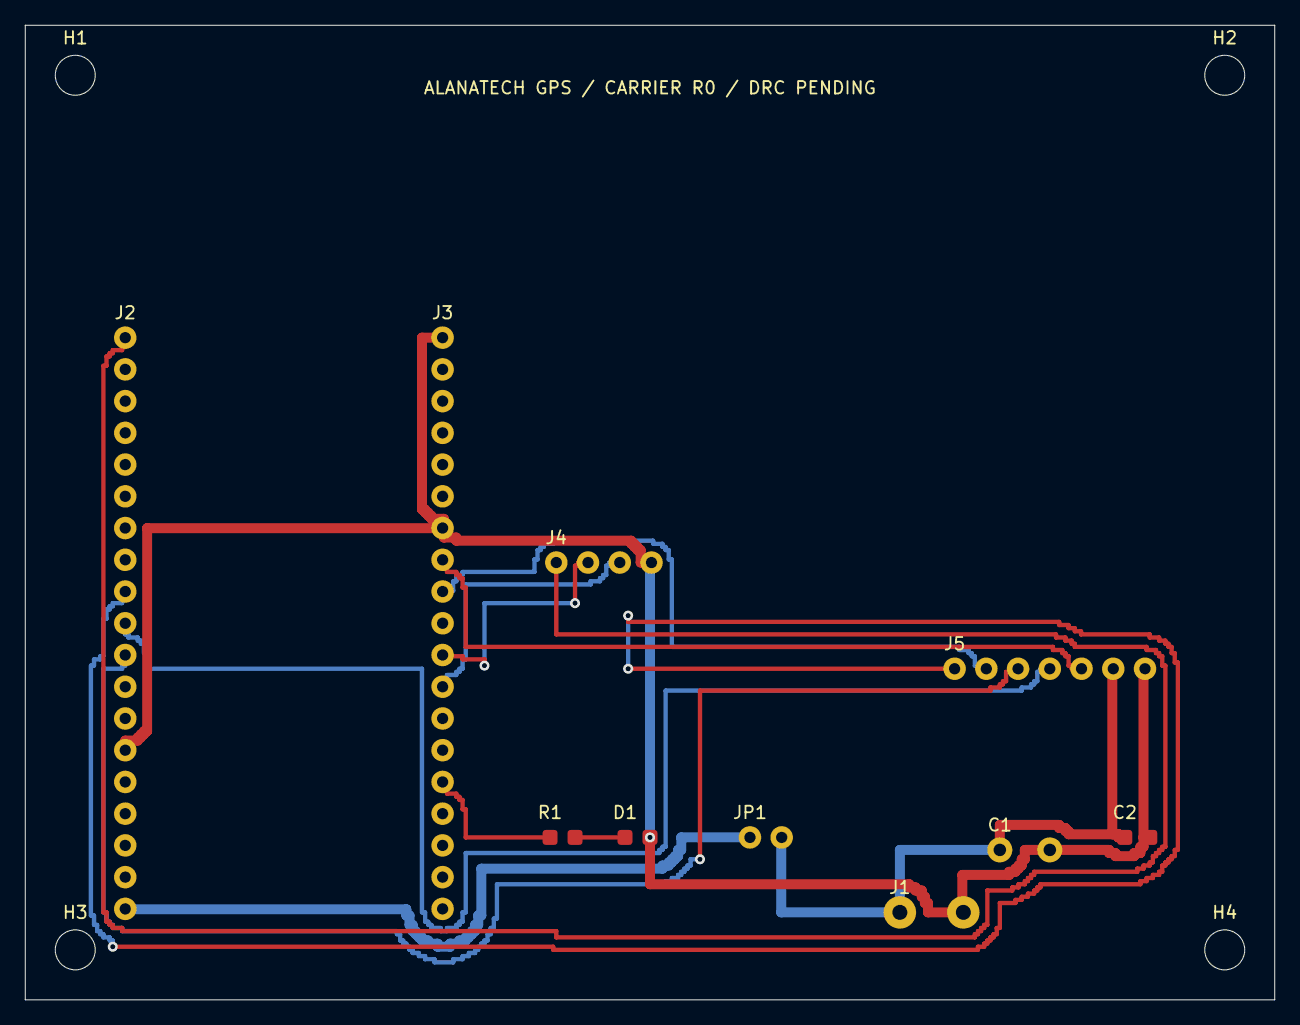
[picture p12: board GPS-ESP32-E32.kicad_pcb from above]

Board: 2 copper layers, 100.0 x 78.0 mm, 14 parts (0 on the bottom side), 13 nets.

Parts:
C1: 1000uF_10V
C2: 100nF_0805
D1: LED_0805
H1, H2, H3, H4: M3
J1: 5V_INPUT_2A
J2: ESP32_J2_1x19
J3: ESP32_J3_1x19
J4: NEO6M_SOCKET_1x04
J5: E32_SOCKET_1x07_RIGHT_ANGLE
JP1: REMOVE_FOR_USB
R1: 330R_0805

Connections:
+3V3: J2.1, J4.1
+5V_ESP: J2.19, JP1.1
+5V_MAIN: C1.1, C2.1, J1.1, J5.6, JP1.2
E32_AUX: J3.8, J5.5
E32_M0: J2.9, J5.1
E32_M1: J3.9, J5.2
E32_RXD: J2.11, J5.3
E32_TXD: J2.10, J5.4
GND: C1.2, C2.2, D1.2, J1.2, J2.14, J3.1, J3.7, J4.4, J5.7
GPS_RX: J3.11, J4.2
GPS_TX: J3.12, J4.3
LED_A: D1.1, R1.2
LED_GPIO: J3.15, R1.1

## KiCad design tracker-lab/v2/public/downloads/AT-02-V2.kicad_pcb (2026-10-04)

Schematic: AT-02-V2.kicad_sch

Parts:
C1: 100nF / VDD1
C2: 100nF / VDD24
C3: 100nF / VDD48
C4: 100nF / USB VDD
C5: 100nF / VDDA
C6: 4.7uF / MCU
C7: 100nF / reset
C8: 100nF / ADC
C9: 1uF / GNSS VIO
C10: 10uF / GNSS VCC
C11: 1uF / GNSS backup
C12: 100nF / motion
C13: 10uF / motion
C14: 10uF / USB IN
C15: 10uF / battery
C16: 22uF / VSYS
C17: 10uF / buck-boost IN
C18, C19: 22uF / buck-boost OUT
C20: 100uF / radio buffer
C21: 100nF / radio
D1: Green LED / status
FB1: Ferrite / analog supply
J1: USB-C / USB 2.0
J2: LiPo / NTC · 3 контакта
J3: GNSS RF / u.FL
J4: SWD / pogo
L1: Дроссель 2.2 µH
R1: 5.1k / CC1
R2: 5.1k / CC2
R3: 22R / USB D+
R4: 22R / USB D-
R5: 10k / BOOT0
R6: 10k / NRST
R7: 1M / battery divider
R8: 330k / battery divider
R9: 10k / I2C SCL
R10: 10k / I2C SDA
R11: 330R / LED
R12: 100k / EN1 default
R13: 2.94k / ISET 300mA target
R14: 3.24k / ILIM
R15: 46.4k / safety timer
R16: 1k / ITERM
R17: 10k / CHG pullup
R18: 100R / GNSS QOD
R19: 10k / radio reset pullup
R20: 100k / M0 pulldown
R21: 100k / M1 pulldown
SW1: BOOT / DFU
SW2: RESET
U1: STM32L072CBT6
U2: u-blox MAX-M10S
U3: EBYTE E32-433T20S
U4: TI BQ24074
U5: TI TPS63031
U6: ST LIS2DW12
U7: TI TPS22919
U8: USBLC6-2SC6 / ESD

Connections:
+3V3: C1.1, C2.1, C3.1, C4.1, C6.1, C11.1, C12.1, C13.1, C18.1, C19.1, C20.1, C21.1, FB1.1, J4.1 (+3V3), R6.2, R9.2, R10.2, R17.2, R19.2, SW1.2 (3V3), U1.1 (VDD), U1.24 (VDD), U1.36 (VDD_USB), U1.48 (VDD), U2.6 (V_BCKP), U3.25 (VCC), U5.1 (VOUT), U5.10 (FB), U6.2 (CS), U6.9 (VDD), U6.10 (VDD_IO), U7.1 (VIN)
+3V3_A: C5.1, FB1.2, U1.9 (VDDA)
+3V3_GNSS: C9.1, C10.1, R18.2, U2.7 (V_IO), U2.8 (VCC), U7.6 (VOUT)
BAT_NTC: J2.3 (BAT_NTC), U4.1 (TS)
BOOT0: R5.1, SW1.1 (BOOT0), U1.44 (BOOT0)
CHARGE_EN1: R12.1, U1.45 (PB8), U4.6 (EN1)
CHG_ILIM: R14.1, U4.12 (ILIM)
CHG_ISET: R13.1, U4.16 (ISET)
CHG_ITERM: R16.1, U4.15 (ITERM)
CHG_STATUS: R17.1, U1.46 (PB9), U4.9 (CHG)
CHG_TMR: R15.1, U4.14 (TMR)
GND: C1.2, C2.2, C3.2, C4.2, C5.2, C6.2, C7.2, C8.2, C9.2, C10.2, C11.2, C12.2, C13.2, C14.2, C15.2, C16.2, C17.2, C18.2, C19.2, C20.2, C21.2, D1.2, J1.A1, J1.A12, J1.B1, J1.B12, J1.S1 (SHIELD), J1.S2 (SHIELD), J1.S3 (SHIELD), J1.S4 (SHIELD), J2.2 (GND), J3.2 (GND), J3.3 (GND), J4.5 (GND), R1.2, R2.2, R5.2, R8.2, R12.2, R13.2, R14.2, R15.2, R16.2, R20.2, R21.2, SW2.2 (GND), U1.8 (VSSA), U1.23 (VSS), U1.35 (VSS), U1.47 (VSS), U2.1 (GND), U2.10 (GND), U2.12 (GND), U3.2 (GND), U3.8 (GND), U3.11 (GND), U3.13 (GND), U3.14 (GND), U3.15 (GND), U3.16 (GND), U3.19 (GND), U3.26 (GND), U4.4 (CE), U4.5 (EN2), U4.8 (VSS), U4.17 (EP), U5.3 (PGND), U5.7 (PS_SYNC), U5.9 (GND), U5.11 (EP), U6.3 (SDO_SA0), U6.6 (GND), U6.7 (RES), U6.8 (GND), U7.2 (GND), U8.2
GNSS_EN: U1.16 (PA6), U7.3 (ON)
GNSS_PPS: U1.17 (PA7), U2.4 (TIMEPULSE)
GNSS_QOD: R18.1, U7.4 (QOD)
GNSS_RF: J3.1 (RF), U2.11 (RF_IN)
GNSS_RX: U1.30 (PA9), U2.3 (RXD)
GNSS_TX: U1.31 (PA10), U2.2 (TXD)
I2C_SCL: R9.1, U1.42 (PB6), U6.1 (SCL)
I2C_SDA: R10.1, U1.43 (PB7), U6.4 (SDA)
LED_A: D1.1, R11.2
LED_DRIVE: R11.1, U1.41 (PB5)
MOTION_INT: U1.19 (PB1), U6.12 (INT1)
NRST: C7.1, J4.4 (NRST), R6.1, SW2.1 (NRST), U1.7 (NRST)
RADIO_AUX: U1.11 (PA1), U3.24 (AUX)
RADIO_M0: R20.1, U1.14 (PA4), U3.20 (M0)
RADIO_M1: R21.1, U1.15 (PA5), U3.21 (M1)
RADIO_RESET: R19.1, U1.18 (PB0), U3.1 (RESET)
RADIO_RX: U1.12 (PA2), U3.22 (RXD)
RADIO_TX: U1.13 (PA3), U3.23 (TXD)
SWCLK: J4.3 (SWCLK), U1.37 (PA14)
SWDIO: J4.2 (SWDIO), U1.34 (PA13)
SW_L1: L1.1 (L1), U5.4 (L1)
SW_L2: L1.2 (L2), U5.2 (L2)
USB_CC1: J1.A5, R1.1
USB_CC2: J1.B5, R2.1
USB_DM: R4.2, U1.32 (PA11)
USB_DM_CONN: J1.A7, J1.B7, R4.1, U8.3, U8.4
USB_DP: R3.2, U1.33 (PA12)
USB_DP_CONN: J1.A6, J1.B6, R3.1, U8.1, U8.6
VBAT: C15.1, J2.1 (VBAT), R7.1, U4.2 (BAT), U4.3 (BAT)
VBAT_ADC: C8.1, R7.2, R8.1, U1.10 (PA0)
VBUS: C14.1, J1.A4, J1.A9, J1.B4, J1.B9, U4.13 (IN), U8.5
VSYS: C16.1, C17.1, U4.10 (OUT), U4.11 (OUT), U5.5 (VIN), U5.6 (EN), U5.8 (VINA)

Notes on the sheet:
AT-02 V2 A0 - CONNECTIVITY DRAFT / Verify package lands, RF, ERC pin types and complete routing before release

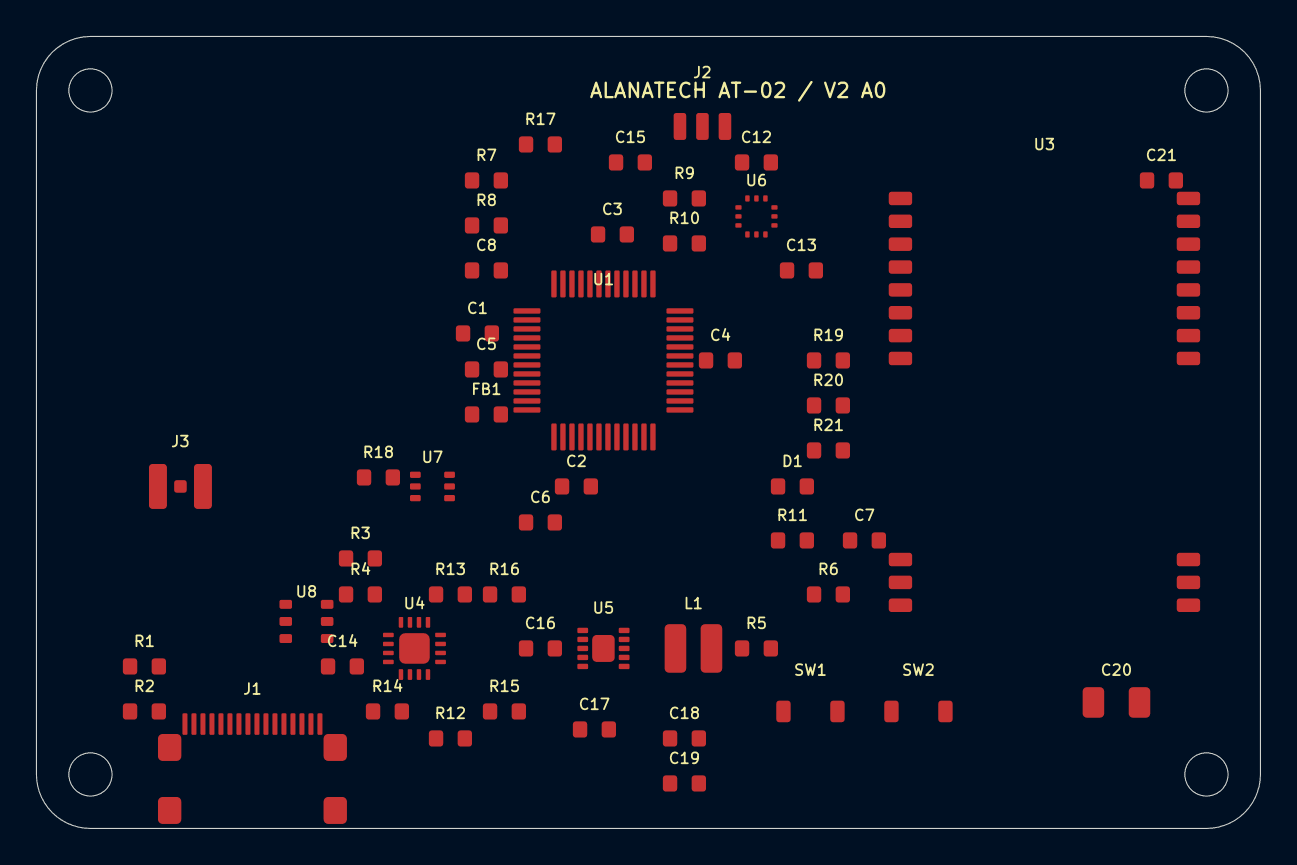
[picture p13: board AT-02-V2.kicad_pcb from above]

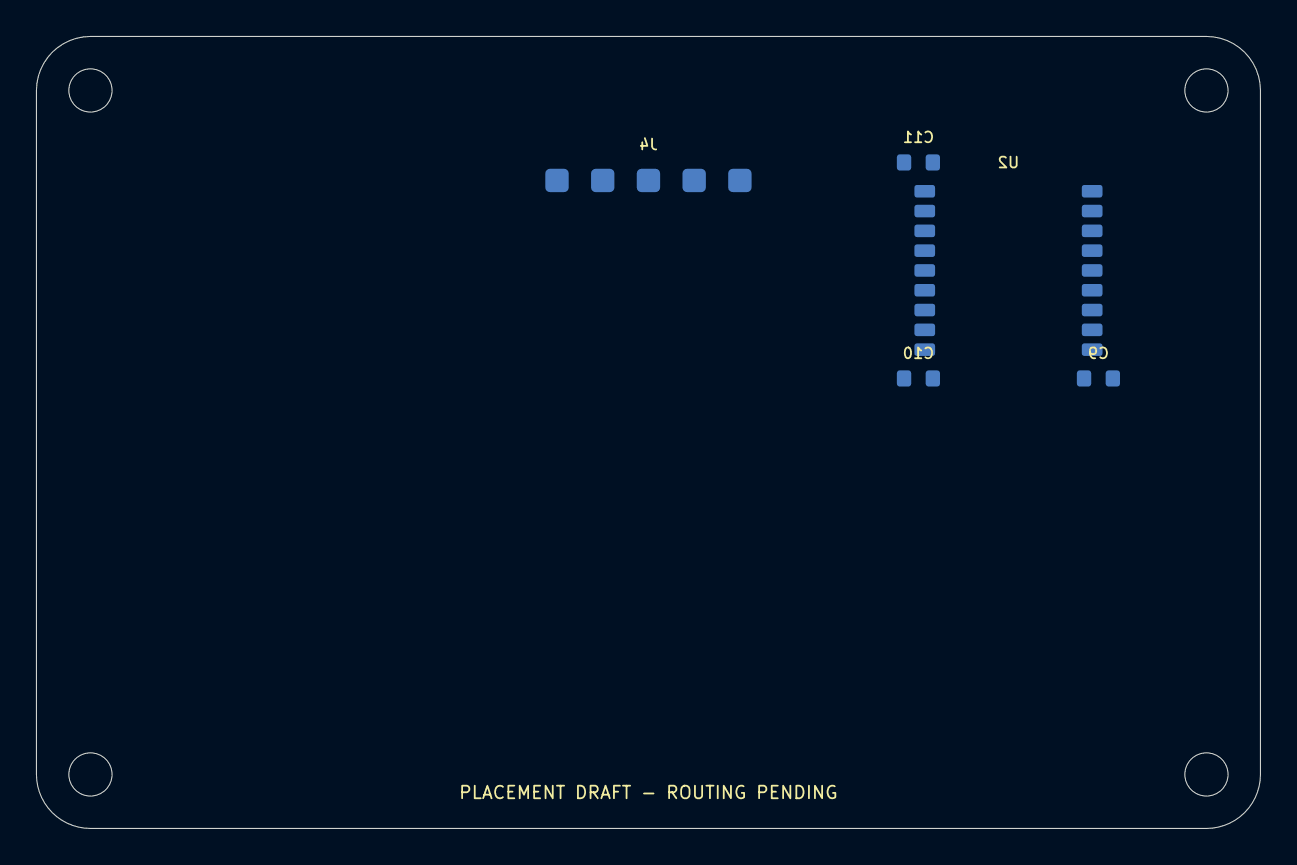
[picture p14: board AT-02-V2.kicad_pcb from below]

Board: 4 copper layers, 68.0 x 44.0 mm, 59 parts (5 on the bottom side), 44 nets, no tracks yet.

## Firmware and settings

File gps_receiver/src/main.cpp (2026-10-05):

// Приёмник: принимает пакеты от GPS-трекера через E32 и показывает их по Wi-Fi.
//   http://<IP>/            — карта и таблица
//   http://<IP>/api/last    — последний пакет (JSON)
//   http://<IP>/api/history — трек [[lat,lon],...] (JSON)
//   http://<IP>/api/status  — статистика приёма и Wi-Fi (JSON)
#include <Arduino.h>
#include <ESPmDNS.h>
#include <WebServer.h>
#include <WiFi.h>

#include "E32.h"
#include "GpsProtocol.h"
#include "config.h"
#include "web_page.h"

static E32 lora(Serial2, E32_RX_PIN, E32_TX_PIN, E32_M0_PIN, E32_M1_PIN, E32_AUX_PIN);
static WebServer server(80);
static bool loraOk = false;

// ---- состояние приёма ----
static gpsproto::Packet last;
static bool hasLast = false;
static uint32_t lastRxMs = 0;
static uint32_t rxOk = 0, rxBad = 0, rxLost = 0;
static int32_t lastSeqById[100];  // -1 = ещё не видели

struct Point {
  float lat, lon;
};
static Point history[HISTORY_SIZE];
static size_t historyLen = 0, historyHead = 0;

static char line[96];
static size_t lineLen = 0;
static uint32_t lineLastByteMs = 0;

// ---------------------------------------------------------------------------

static void onPacket(const gpsproto::Packet& p) {
  rxOk++;
  int32_t& prev = lastSeqById[p.deviceId];
  if (prev >= 0 && p.seq != (uint16_t)prev) {
    uint16_t lost = gpsproto::lostBetween((uint16_t)prev, p.seq);
    if (lost < 1000) rxLost += lost;  // большой скачок = трекер перезагрузился
  }
  prev = p.seq;

  last = p;
  hasLast = true;
  lastRxMs = millis();

  if (p.fix) {
    history[historyHead] = {(float)p.lat, (float)p.lon};
    historyHead = (historyHead + 1) % HISTORY_SIZE;
    if (historyLen < HISTORY_SIZE) historyLen++;
  }

  Serial.printf("[RX] id=%u seq=%u fix=%d lat=%.6f lon=%.6f alt=%d м скорость=%.1f км/ч спутн=%u "
                "hdop=%.1f | ок=%lu плохих=%lu потеряно=%lu\n",
                p.deviceId, p.seq, p.fix, p.lat, p.lon, p.altM, p.speedKmh, p.sats, p.hdop,
                (unsigned long)rxOk, (unsigned long)rxBad, (unsigned long)rxLost);
}

static void onLine() {
  line[lineLen] = 0;
  gpsproto::Packet p;
  if (gpsproto::decode(line, p)) {
    onPacket(p);
  } else if (lineLen > 0) {
    rxBad++;
    Serial.printf("[RX] плохой пакет (%u байт): %s\n", (unsigned)lineLen, line);
  }
  lineLen = 0;
}

static void pollLora() {
  while (lora.serial().available()) {
    char c = (char)lora.serial().read();
    lineLastByteMs = millis();
    if (c == '\n') {
      digitalWrite(LED_PIN, HIGH);
      onLine();
      digitalWrite(LED_PIN, LOW);
    } else if (c != '\r') {
      if (lineLen < sizeof(line) - 1) {
        line[lineLen++] = c;
      } else {  // слишком длинная строка — мусор
        rxBad++;
        lineLen = 0;
      }
    }
  }
  // обрывок пакета без '\n' — выбрасываем через 1 с
  if (lineLen > 0 && millis() - lineLastByteMs > 1000) onLine();
}

// ---- HTTP ------------------------------------------------------------------

static void sendJson(const String& body) {
  server.sendHeader("Access-Control-Allow-Origin", "*");
  server.sendHeader("Cache-Control", "no-store");
  server.send(200, "application/json", body);
}

static void handleLast() {
  if (!hasLast) {
    sendJson("{\"has_data\":false}");
    return;
  }
  char buf[320];
  snprintf(buf, sizeof(buf),
           "{\"has_data\":true,\"id\":%u,\"seq\":%u,\"fix\":%s,\"lat\":%.6f,\"lon\":%.6f,"
           "\"alt\":%d,\"speed\":%.1f,\"sats\":%u,\"hdop\":%.1f,\"age_s\":%lu,\"online\":%s}",
           last.deviceId, last.seq, last.fix ? "true" : "false", last.lat, last.lon, last.altM,
           last.speedKmh, last.sats, last.hdop, (unsigned long)((millis() - lastRxMs) / 1000),
           millis() - lastRxMs < TRACKER_TIMEOUT_S * 1000UL ? "true" : "false");
  sendJson(buf);
}

static void handleHistory() {
  String s;
  s.reserve(historyLen * 24 + 4);
  s += '[';
  size_t start = (historyHead + HISTORY_SIZE - historyLen) % HISTORY_SIZE;
  char buf[32];
  for (size_t i = 0; i < historyLen; i++) {
    const Point& pt = history[(start + i) % HISTORY_SIZE];
    snprintf(buf, sizeof(buf), "%s[%.6f,%.6f]", i ? "," : "", pt.lat, pt.lon);
    s += buf;
  }
  s += ']';
  sendJson(s);
}

static void handleStatus() {
  char buf[320];
  snprintf(buf, sizeof(buf),
           "{\"uptime_s\":%lu,\"lora_ok\":%s,\"rx_ok\":%lu,\"rx_bad\":%lu,\"rx_lost\":%lu,"
           "\"wifi_rssi\":%d,\"ip\":\"%s\",\"free_heap\":%lu}",
           (unsigned long)(millis() / 1000), loraOk ? "true" : "false", (unsigned long)rxOk,
           (unsigned long)rxBad, (unsigned long)rxLost, WiFi.RSSI(),
           WiFi.localIP().toString().c_str(), (unsigned long)ESP.getFreeHeap());
  sendJson(buf);
}

static void handleReset() {
  rxOk = rxBad = rxLost = 0;
  historyLen = historyHead = 0;
  for (auto& s : lastSeqById) s = -1;
  sendJson("{\"ok\":true}");
}

// ---- Wi-Fi -----------------------------------------------------------------

// Код причины последнего отключения (201 = сеть не найдена, 15/204 = неверный пароль и т.д.)
static volatile int lastDisconnectReason = 0;

// Печатает видимые сети — помогает понять, видит ли ESP32 нужную (ESP32 работает только на 2.4 ГГц).
static void scanWifi() {
  Serial.println("[WiFi] сканирую сети...");
  WiFi.disconnect();  // сканирование не работает, пока идут попытки подключения
  delay(100);
  int n = WiFi.scanNetworks();
  Serial.printf("[WiFi] найдено сетей: %d\n", n);
  bool found = false;
  for (int i = 0; i < n; i++) {
    bool match = WiFi.SSID(i) == WIFI_SSID;
    found |= match;
    Serial.printf("  %s \"%s\"  %d дБм  канал %d  %s\n", match ? ">>" : "  ", WiFi.SSID(i).c_str(),
                  WiFi.RSSI(i), WiFi.channel(i),
                  WiFi.encryptionType(i) == WIFI_AUTH_OPEN ? "открытая" : "с паролем");
  }
  if (!found) {
    Serial.printf("[WiFi] сеть \"%s\" не видна. Проверьте имя (регистр, пробелы) и что роутер вещает 2.4 ГГц\n",
                  WIFI_SSID);
  }
  WiFi.scanDelete();
  WiFi.begin(WIFI_SSID, WIFI_PASSWORD);
}

static void connectWifi() {
  WiFi.onEvent([](WiFiEvent_t, WiFiEventInfo_t info) {
    lastDisconnectReason = info.wifi_sta_disconnected.reason;
  }, ARDUINO_EVENT_WIFI_STA_DISCONNECTED);
  WiFi.mode(WIFI_STA);
  WiFi.setAutoReconnect(true);
  WiFi.setHostname(MDNS_NAME);
  WiFi.begin(WIFI_SSID, WIFI_PASSWORD);
  Serial.printf("[WiFi] подключение к \"%s\"", WIFI_SSID);
  uint32_t start = millis();
  while (WiFi.status() != WL_CONNECTED && millis() - start < 20000) {
    delay(500);
    Serial.print('.');
  }
  Serial.println();
  if (WiFi.status() == WL_CONNECTED) {
    Serial.printf("[WiFi] подключено, IP: %s, RSSI: %d дБм\n",
                  WiFi.localIP().toString().c_str(), WiFi.RSSI());
  } else {
    Serial.printf("[WiFi] !!! не удалось подключиться (причина: %d), продолжаю попытки в фоне\n",
                  lastDisconnectReason);
    scanWifi();
  }
}

static void pollWifi() {
  static bool wasConnected = false;
  static uint32_t lastOkOrTry = 0;
  bool c = WiFi.status() == WL_CONNECTED;
  if (c && !wasConnected) {
    Serial.printf("[WiFi] подключено, IP: %s — откройте http://%s/ или http://%s.local/\n",
                  WiFi.localIP().toString().c_str(), WiFi.localIP().toString().c_str(), MDNS_NAME);
  } else if (!c && wasConnected) {
    Serial.printf("[WiFi] соединение потеряно (причина: %d), переподключаюсь\n", lastDisconnectReason);
  }
  // Обычно ESP32 переподключается сама (setAutoReconnect). Вмешиваемся, только если не вышло за 20 с.
  if (c) {
    lastOkOrTry = millis();
  } else if (millis() - lastOkOrTry > 20000) {
    lastOkOrTry = millis();
    Serial.println("[WiFi] перезапускаю подключение");
    WiFi.disconnect();
    WiFi.begin(WIFI_SSID, WIFI_PASSWORD);
  }
  wasConnected = c;
}

// ---------------------------------------------------------------------------

void setup() {
  Serial.begin(115200);
  delay(300);
  pinMode(LED_PIN, OUTPUT);
  for (auto& s : lastSeqById) s = -1;
  Serial.println();
  Serial.println("=== AlanaTech GPS приёмник ===");

  loraOk = lora.begin();
  if (!loraOk) {
    Serial.println("[E32] !!! модуль не отвечает (AUX не поднялся). Проверьте питание 5 В и M0/M1/AUX");
  }
  E32::Config actual{};
  if (lora.ensureConfig(E32::defaultConfig(E32_POWER), &actual)) {
    Serial.printf("[E32] конфигурация ОК: ADDH=%02X ADDL=%02X SPED=%02X CHAN=%02X (%u МГц) OPTION=%02X\n",
                  actual.addh, actual.addl, actual.sped, actual.chan, 410 + actual.chan,
                  actual.option);
  } else {
    Serial.println("[E32] !!! не удалось прочитать/записать конфигурацию. Проверьте RX/TX провода");
    loraOk = false;
  }

  connectWifi();
  if (MDNS.begin(MDNS_NAME)) MDNS.addService("http", "tcp", 80);

  server.on("/", [] { server.send_P(200, "text/html; charset=utf-8", WEB_PAGE); });
  server.on("/api/last", handleLast);
  server.on("/api/history", handleHistory);
  server.on("/api/status", handleStatus);
  server.on("/api/reset", HTTP_POST, handleReset);
  server.onNotFound([] { server.send(404, "text/plain", "not found"); });
  server.begin();
  Serial.println("[HTTP] сервер запущен, жду пакеты от трекера...");
}

void loop() {
#if TX_TEST
  static uint32_t lastPingMs = 0, pingN = 0;
  if (loraOk && millis() - lastPingMs >= 3000) {
    lastPingMs = millis();
    char b[24];
    int n = snprintf(b, sizeof(b), "PING %lu\n", (unsigned long)pingN++);
    lora.serial().write((const uint8_t*)b, n);
    lora.serial().flush();
    Serial.printf("[TX_TEST] %s", b);
  }
#endif
  pollLora();
  pollWifi();
  server.handleClient();

  static uint32_t lastWarn = 0;
  if (millis() - lastWarn > 30000) {
    lastWarn = millis();
    if (!hasLast) {
      Serial.println("[RX] пакетов пока нет. Трекер включён? Одинаковый канал/адрес на обоих E32?");
    } else if (millis() - lastRxMs > TRACKER_TIMEOUT_S * 1000UL) {
      Serial.printf("[RX] нет пакетов уже %lu с\n", (unsigned long)((millis() - lastRxMs) / 1000));
    }
  }
}

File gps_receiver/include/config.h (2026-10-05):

// Настройки приёмника (ESP32 + E32-433T30D + Wi-Fi)
#pragma once

// ---- Wi-Fi ----
#define WIFI_SSID "New BilimLand Wi-Fi"  // регистр важен!
#define WIFI_PASSWORD "astana2023"
#define MDNS_NAME "alanatech-gps"  // http://alanatech-gps.local

// ---- E32-433T30D (UART2) ----
#define E32_RX_PIN 16   // <- TXD модуля E32
#define E32_TX_PIN 17   // -> RXD модуля E32
#define E32_M0_PIN 25
#define E32_M1_PIN 26
#define E32_AUX_PIN 27  // если AUX не подключён, тоже работает (вход с подтяжкой)

// Мощность E32 (0 = 30 дБм ... 3 = 21 дБм). Влияет только на передачу (env:tx_test).
#ifndef E32_POWER
#define E32_POWER 0
#endif

// TX_TEST=1 — приёмник сам шлёт "PING <n>" раз в 3 с: проверка эфира в обратную сторону.
#ifndef TX_TEST
#define TX_TEST 0
#endif

#define LED_PIN 2  // мигает при каждом принятом пакете

// Сколько последних точек хранить для трека на карте
#define HISTORY_SIZE 200

// Через сколько секунд без пакетов считать трекер "не в сети"
#define TRACKER_TIMEOUT_S 30

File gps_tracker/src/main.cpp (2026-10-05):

// GPS-трекер: читает NEO-6M и каждые SEND_INTERVAL_MS отправляет координаты через E32.
#include <Arduino.h>
#include <TinyGPSPlus.h>
#include <math.h>

#include "E32.h"
#include "GpsProtocol.h"
#include "config.h"

static TinyGPSPlus gps;
static HardwareSerial gpsSerial(1);
static E32 lora(Serial2, E32_RX_PIN, E32_TX_PIN, E32_M0_PIN, E32_M1_PIN, E32_AUX_PIN);

static uint16_t seq = 0;
static uint32_t lastSendMs = 0;
static bool loraOk = false;

static void printConfig(const E32::Config& c) {
  Serial.printf("[E32] ADDH=%02X ADDL=%02X SPED=%02X CHAN=%02X (%u MHz) OPTION=%02X\n", c.addh,
                c.addl, c.sped, c.chan, 410 + c.chan, c.option);
}

static gpsproto::Packet makePacket() {
  gpsproto::Packet p;
  p.deviceId = DEVICE_ID;
  p.seq = seq;
#if FAKE_GPS
  // Круг радиусом ~500 м вокруг центра Астаны, один оборот за 5 минут.
  float a = (millis() % 300000UL) / 300000.0f * 2.0f * (float)M_PI;
  p.fix = true;
  p.lat = 51.128207 + 0.0045 * sin(a);
  p.lon = 71.430411 + 0.0072 * cos(a);
  p.altM = 347;
  p.speedKmh = 37.7f;
  p.sats = 9;
  p.hdop = 0.9f;
#else
  p.fix = gps.location.isValid() && gps.location.age() < 3000;
  if (gps.location.isValid()) {  // последняя известная точка, даже если фикс потерян
    p.lat = gps.location.lat();
    p.lon = gps.location.lng();
  }
  if (gps.altitude.isValid()) p.altM = (int16_t)lround(gps.altitude.meters());
  if (gps.speed.isValid()) p.speedKmh = (float)gps.speed.kmph();
  if (gps.satellites.isValid()) p.sats = (uint8_t)min<uint32_t>(gps.satellites.value(), 99);
  p.hdop = gps.hdop.isValid() ? (float)gps.hdop.hdop() : 99.9f;
#endif
  return p;
}

static void sendPacket() {
  if (!loraOk) {
    Serial.println("[TX] пропуск: E32 не настроен, перезапустите после проверки питания и разъёмов");
    return;
  }
  char buf[gpsproto::kBufferSize];
  gpsproto::Packet p = makePacket();
  int n = gpsproto::encode(p, buf, sizeof(buf));
  if (n < 0) {
    Serial.println("[TX] ошибка кодирования пакета");
    return;
  }
  if (!lora.waitAux(2000)) {
    Serial.println("[TX] пропуск: E32 занят (AUX=LOW)");
    return;
  }

  digitalWrite(LED_PIN, HIGH);
  lora.serial().write((const uint8_t*)buf, n);
  lora.serial().flush();
  digitalWrite(LED_PIN, LOW);

  Serial.printf("[TX] %.*s", n, buf);  // buf уже содержит '\n'
  seq++;
}

static void printGpsStatus() {
#if !FAKE_GPS
  Serial.printf("[GPS] символов=%lu, NMEA ок=%lu, ошибок CRC=%lu, спутников=%lu, фикс=%s\n",
                (unsigned long)gps.charsProcessed(), (unsigned long)gps.passedChecksum(),
                (unsigned long)gps.failedChecksum(),
                (unsigned long)(gps.satellites.isValid() ? gps.satellites.value() : 0),
                gps.location.isValid() ? "да" : "нет");
  if (millis() > 5000 && gps.charsProcessed() < 10) {
    Serial.println("[GPS] !!! нет данных от NEO-6M — проверьте питание и провод TX модуля -> GPIO"
                   " " + String(GPS_RX_PIN));
  }
#endif
}

void setup() {
  Serial.begin(115200);
  delay(300);
  pinMode(LED_PIN, OUTPUT);
  Serial.println();
  Serial.printf("=== AlanaTech GPS трекер, ID=%d%s ===\n", DEVICE_ID,
                FAKE_GPS ? " (ТЕСТОВЫЕ КООРДИНАТЫ)" : "");

#if !FAKE_GPS
  gpsSerial.begin(GPS_BAUD, SERIAL_8N1, GPS_RX_PIN, GPS_TX_PIN);
#endif

  loraOk = lora.begin();
  if (!loraOk) {
    Serial.println("[E32] !!! модуль не отвечает (AUX не поднялся). Проверьте питание 5 В и M0/M1/AUX");
  }
  E32::Config actual{};
  if (lora.ensureConfig(E32::defaultConfig(E32_POWER), &actual)) {
    loraOk = true;
    Serial.println("[E32] конфигурация ОК");
    printConfig(actual);
  } else {
    Serial.println("[E32] !!! не удалось прочитать/записать конфигурацию. Проверьте RX/TX провода");
    loraOk = false;
  }
}

void loop() {
#if !FAKE_GPS
  while (gpsSerial.available()) gps.encode(gpsSerial.read());
#endif

  // Всё, что пришло по радио, просто печатаем (на будущее — команды от приёмника).
  while (lora.serial().available()) Serial.write(lora.serial().read());

  uint32_t now = millis();
  if (now - lastSendMs >= SEND_INTERVAL_MS) {
    lastSendMs = now;
    printGpsStatus();
    sendPacket();
  }
}

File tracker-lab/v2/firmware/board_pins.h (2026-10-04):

#ifndef AT02_BOARD_PINS_H
#define AT02_BOARD_PINS_H
/* STM32L072CBT6 / LQFP48; alternate functions verified in STM32 DS10689.
 * Port driver must configure these with CMSIS/LL and high-impedance GNSS UART
 * when +3V3_GNSS is off. This file does not initialize peripherals. */
#define AT_GNSS_UART "USART1: PA9 TX(AF4), PA10 RX(AF4), 9600 8N1"
#define AT_RADIO_UART "USART2: PA2 TX(AF4), PA3 RX(AF4), 9600 8N1"
#define AT_I2C "I2C1: PB6 SCL(AF1), PB7 SDA(AF1)"
#define AT_RADIO_AUX "PA1"
#define AT_RADIO_M0 "PA4"
#define AT_RADIO_M1 "PA5"
#define AT_RADIO_RESET "PB0"
#define AT_GNSS_ENABLE "PA6"
#define AT_GNSS_PPS "PA7"
#define AT_MOTION_INTERRUPT "PB1 / EXTI1"
#define AT_BATTERY_ADC "PA0 / ADC_IN0 / divider 1M:330k"
#define AT_LED "PB5"
#define AT_CHARGE_EN1 "PB8 / default LOW USB100; HIGH only after permitted USB budget"
#define AT_CHARGE_STATUS "PB9 / active LOW open-drain"
#define AT_USB "PA11 DM, PA12 DP / HSI48 + CRS"
#define AT_SWD "PA13 SWDIO, PA14 SWCLK, NRST"
#endif

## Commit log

2026-09-27 Пины E32 и GPS под новое подключение
2026-10-05 New UpDate KiCAd
    [BOM.csv, GPS-ESP32-E32.kicad_pcb, GPS-ESP32-E32.kicad_sch]
